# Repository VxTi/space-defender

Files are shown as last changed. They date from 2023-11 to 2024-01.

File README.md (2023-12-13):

# 🎮 TI Game Controller

De opdracht van Technische Informatica (TI) bestaat uit het ontwikkelen van een niet al te ingewikkelde browser-spel welke je gaat aansturen met je zelf gemaakt controller!

Aan dit project werk je in een tweetal, waarbij je onze Gitlab omgeving gebruikt
voor het bijhouden van je code, documentatie en planning.

## 📁 Bestandsstructuur

In deze repository krijgen jullie een structuur aan bestanden, hierbij mag je zelf wijzigingen maken in de bestanden die je nodig hebt.
De structuur is als volgt:

- `docs`: Hierin kan je de documentatie kwijt voor jouw project. Hiervan wordt een website gegenereerd die je kan vinden onder 'Pages' (Deploy > Pages).
- `teamdocumentatie`: In deze map kan je (markdown!) documenten kwijt die gaan over de samenwerking in het team, wat je niet op je gegenereerde website wilt hebben.
- `arduino`: Hierin kan je de code kwijt voor jouw project wat te maken heeft met je embedded systeem, code geschreven in Arduino.
- `web`: Hierin kan je de code kwijt voor jouw project wat te maken heeft met de webapplicatie, bijvoorbeeld HTML, CSS en Javascript.
- `server`: Hier kan je je server applicatie kwijt die gaat zorgen voor de verbinding tussen jouw embedded systeem, web-applicatie en database.

## 📝 Opdracht

De opdracht vinden jullie in de map `docs` onder `opdracht.md`. Hierin staat de opdracht beschreven en de eisen waaraan je moet voldoen. Beter is om de opdracht te bekijken via `Deploy` > `Pages`, en vervolgens te navigeren naar de opdracht.

Daarnaast vind je in dit Gitlab-project:

- User Stories (Plan > Issues)
- Learning Stories (Plan > Issues)
- Scrum Board (Plan > Boards)
- Sprints (Plan > Milestones)

## 📚 Documentatie

Naast het schrijven van commentaar in je code ga je ook aan de slag met het schrijven van documentatie. Dit doe je door in de map `docs` een Markdown bestand aan te maken. Dit bestand wordt automatisch omgezet naar een website die je kan vinden onder 'Pages' (Deploy > Pages).

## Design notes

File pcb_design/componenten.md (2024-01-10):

# Componenten

RGB LED: https://www.tinytronics.nl/shop/nl/componenten/led's/led's/rgb-led-5mm-diffuus-common-cathode
Battery level: https://randomnerdtutorials.com/power-esp32-esp8266-solar-panels-battery-level-monitoring/

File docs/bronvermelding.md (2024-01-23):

# Bronvermelding

## Informatiebronnen
- Wikipedia | Defender<br>
  https://en.wikipedia.org/wiki/Defender_(1981_video_game)

- KiCad | Introduction to KiCad<br>
  https://docs.kicad.org/6.0/en/getting_started_in_kicad/getting_started_in_kicad.html

- Squidfunk | MkDocs Material<br>
  https://squidfunk.github.io/mkdocs-material/reference/

- Sidorares | node-mysql2 Documentation<br>
  https://sidorares.github.io/node-mysql2/docs/documentation

- Random Nerd Tutorials | Power ESP32/ESP8266 with Solar Panels and Battery Level Monitoring<br>
  https://randomnerdtutorials.com/power-esp32-esp8266-solar-panels-battery-level-monitoring/

- Hackster.io | ESP32 BLE HID Device<br>
  https://www.hackster.io/user0448083246/esp32-ble-hid-keyboard-37a103

- HvA HBO-ICT | Knowledgebase HBO-ICT<br>
  https://knowledgebase.hbo-ict-hva.nl/

## Gebruikte assets
- FreeSound, LittleRobotSoundFactory | 8-Bit Sound Effects Library<br>
  https://freesound.org/people/LittleRobotSoundFactory/packs/16681/

- Dafond | Arcade Ya Font<br>
  https://www.dafont.com/arcade-ya.font

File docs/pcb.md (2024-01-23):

# Custom PCB design

## Inleiding
Voor dit project hebben wij onszelf uitgedaagd om zelf een PCB te ontwerpen voor de game controller. Dit hebben we gedaan met het programma KiCad. Dit is een gratis CAD programma waarmee je PCBs kunt ontwerpen. Het is een open source programma en wordt veel gebruikt door hobbyisten. Het is een erg uitgebreid programma en heeft veel mogelijkheden. Het is een erg goed programma om mee te beginnen als je nog nooit een PCB hebt ontworpen.

## PCB ontwerp
Wij hebben twee ontwerpen gemaakt. De allereerste was best wel mislukt en inefficient. Daarnaast was deze ook veels te groot aangezien we niet goed wisten hoe we het moesten aanpakken. De tweede versie was een stuk beter en efficienter. Deze hebben we ook daadwerkelijk op school laten printen. De eerste versie hebben we niet laten printen omdat deze niet goed was. Hieronder zie je de eerste versie van het PCB ontwerp.

## Designs

!!! note "Versie 1"
    Schematic 1 PCB 1

!!! note "Versie 2"
    Schematic 2 PCB 2

## PCB laten printen
In eerste instantie wilden we de PCB bestellen bij Jlcpcb. Dit is een bedrijf dat PCBs print en ze naar je opstuurt. Het enige nadeel was dat deze uit China moesten komen en dat het dus erg lang zou duren voordat we ze binnen zouden krijgen, daarnaast kost het ook geld. We hebben toen besloten om de PCB te laten printen op school. Dit was gratis en we konden het binnen twee dagen al ophalen. Het enige nadeel aan de PCB die we op school hebben laten printen is dat de kwaliteit niet zo goed is. De koperbanen zijn bloodgesteld en de PCB is niet gelamineerd. Daarnaast zijn de pads niet doorverbonden van de voorkant naar de achterkant, dus als je iets aan de achterkant zou solderen zou de voorkant niet werken. Om deze reden kunnen we helaas niet een werkende draadloze controller laten zien op de product review.

## Onderdelen
Hier een lijst met onderdelen:

| Aantal | Onderdeel |
| :----- | :--- |
| 2x | :material-fence-electric: Female headers 24x1 |
| 1x | :material-chip: ESP32S3 Dev Module |
| 1x | :material-integrated-circuit-chip: TP4056 battery management module  |
| 1x | :material-battery: 1250mAh 3.7V LiPo batterij |
| 1x | :material-toggle-switch: On/Off Switch |
| 7x | :material-gesture-tap-button: Non-Latching Push Button |
| 1x | :material-led-on: RGB LED |
| 1x | :material-resistor: 100 k:material-omega: weerstand |
| 1x | :material-resistor: 27 k:material-omega: weerstand |
| 3x | :material-resistor: 47 :material-omega: weerstand |
| 7x | :material-resistor: 500 :material-omega: weerstand |

## Resultaat
Hieronder zie je het resultaat van de PCB die we op school hebben laten printen. De PCB ziet er niet uit zoals je gewend bent, hij is niet standaard groen en de koperbanen zijn blootgesteld. We hebben alle componenten erop gesoldeerd. Sommige knoppen waarvan de tracks aan de achterkant lopen doen het wel, maar de knoppen waarvan de tracks aan de voorkant lopen doen het niet. Dit komt omdat de pads niet doorverbonden zijn. We hebben de PCB getest met een ESP32S3 Dev Module en de meeste functies werken. Stel dat we een PCB hadden die wel doorverbonden pads had weten we zeker dat dit design een succes was geweest.

Resultaat

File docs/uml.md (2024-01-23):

# UML

## Database EER Diagram
DB

## Class Diagram
Class Diagram

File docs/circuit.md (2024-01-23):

# Elektrische schakeling Game controller

Hieronder is de elektrische schakeling van de game controller te zien. Ook deze hebben wij gemaakt met behulp van het gratis CAD programma KiCad. KiCad heeft zelf al heel veel elektrische componenten ingebouwd waarmee je kunt werken. Helaas konden wij nergens van KiCad zelf de ESP32 vinden. De schematics en blueprints voor alle Espressif (Fabrikant van onder andere de ESP32) zijn te vinden op de GitHub van Espressif. De download link hebben we [hier voor je](https://github.com/espressif/kicad-libraries/releases/download/2.0.6/espressif-kicad-addon.zip).

!!! note "Circuit" 
    Game controller

### Pin Schema
| ESP32 Pin | Doel |
| :--- | :--- |
| `21` | :material-gesture-tap-button: DPAD UP Knop |
| `38` | :material-gesture-tap-button: DPAD LEFT Knop |
| `45` | :material-gesture-tap-button: DPAD RIGHT Knop |
| `42` | :material-gesture-tap-button: DPAD DOWN Knop |
| `7` | :material-gesture-tap-button: Primary A Knop |
| `6` | :material-gesture-tap-button: Secondary B Knop |
| `4` | :material-gesture-tap-button: Option Knop |
| `5` | :material-battery-unknown-bluetooth: Accu spanningsmeter |
| `35` | :material-led-on: RGB LED - Rood PWM Signaal |
| `36` | :material-led-on: RGB LED - Groen PWM Signaal |
| `37` | :material-led-on: RGB LED - Blauw PWM Signaal |

Op dit schema zit alles er wellicht een beetje ongeorganiseerd uit, en dat kan in die zin ook kloppen. Echter heeft dit een reden. Bij het ontwerpen van een PCB moet je altijd eerst een schematic maken zodat het programma weet wat met wat is verbonden. De reden dat wij soms pins op de schematic hebben gekozen die totaal aan de andere kant liggen komt omdat deze dan op de PCB vaak wel recht naast de knopjes bijvoorbeeld liggen. Zo zijn de tracks in de pcb zo kort mogelijk, want lange tracks hebben vaker last van noise en een hoge weerstand.

Het ontwerp in deze schematic is dus ook letterlijk schematisch gemaakt en niet praktisch zoals het PCB ontwerp. De Espressif library maakt hun blueprints dus op deze manier om bepaalde pins met enigzins dezelfde functionaliteit bij elkaar weer te geven zodat het makkelijk is om deze te onderscheiden. Wij maken hier in dit geval geen gebruik van aangezien wij alleen Input en Output pins nodig hebben, en dit ondersteunen alle GPIO Pins op de ESP32 wel.

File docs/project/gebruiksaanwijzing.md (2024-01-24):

# Game controller gebruiksaanwijzing.

Controller

## Inleiding
Dit is de game controller die wij gedurende blok 2 hebben ontwikkeld. Zoals je op de foto kunt zien is de controller geheel draadloos te gebruiken door middel van een Bluetooth Low Energy verbinding. Alle componenten kun je vinden in de PCB documentatie.

## Gebruikswijze
De controller is te gebruiken met alle games die gebruik maken van de WASD toetsenbord layout. De controller emuleert als het ware een Bluetooth toetsenbord, waardoor deze heel makkelijk te implementeren was in ons spel. Daarnaast is deze ook meteen compatible met alle andere games die gebruik maken van de WASD layout.
Wanneer je de controller aanzet met de ON/OFF switch zal deze meteen in koppelmodus (pairing) gaan. Je zult vanzelf op jouw apparaat zien wanneer de controller verbonden is.

## Batterij
De controller maakt gebruik van een 3.7V LiPo batterij. Deze batterij is op te laden met een USB-C kabel met een spanning van 5 Volt. Je kunt dus de meest hedendaagse opladers gebruiken om de controller op te laden. De controller heeft een ingebouwde batterij indicator die je kunt zien wanneer je de controller aan het opladen bent. Dan zal er een rode LED branden op de oplaad module. Wanneer de controller volledig is opgeladen zal deze LED blauw worden.

## Knoppen
De controller heeft 7 knoppen. 4 van deze knoppen zijn de D-PAD knoppen. Deze knoppen zijn de pijltjes toetsen op een toetsenbord. De andere 3 knoppen zijn de A, B en Option knoppen. De A knop emuleert Spatie, en de B knop emuleert F. Tot slot emuleert de Option knop de R knop. Deze knoppen zijn allemaal te zien op de foto hierboven.

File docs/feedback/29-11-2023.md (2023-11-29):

* Feedback op 29-11-2023

** Sebas:

Beweging mag wat sneller, vloeiender
Input lag is naar Sebas' idee niet aanwezig

** Dano:

Ziet er goed uit
Springen mag hoger
Input lag is ook naar Dano's idee ook niet aanwezig

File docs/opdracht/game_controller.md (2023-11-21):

# Game Controller

Wanneer je denkt aan een Game Controller denk je misschien wel aan de controller van jouw favoriete game console. Deze controllers zijn vaak gemaakt van plastic en bevatten een aantal knoppen en joysticks. Onderdeel van deze opdracht is dat jullie zelf een game controller gaan maken, hoe deze echter eruit gaat zien bepalen jullie.

Om jullie een vlotte start te geven met het bouwen krijgen jullie van ons een moederbord waarop ruimte zit voor een aantal vaste componenten. Dit document geeft je alle details over het gebruik van dit moederbord en de componenten die erop zitten. Daarnaast vind je in dit document ook een aantal voorbeelden van hoe je de componenten kan gebruiken.

## Printed Circuit Board (PCB)

Het moederbord dat jullie krijgen is een Printed Circuit Board (PCB). Dit is een bord waarop een aantal componenten zijn geplaatst. Deze componenten zijn met elkaar verbonden door middel van koperen sporen. Deze sporen zorgen ervoor dat de componenten met elkaar kunnen communiceren. Dit zorgt ervoor dat je geen losse draden hoeft te gebruiken om de componenten met elkaar te verbinden, zoals je misschien wel gewend bent van de breadboard.

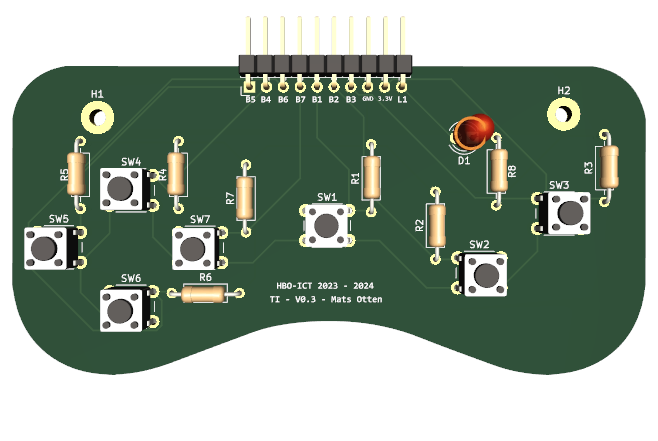
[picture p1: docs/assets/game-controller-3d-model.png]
3d model


## Ontwerp

Bij het ontwerp van de PCB is er rekening gehouden met vooral drukknoppen die op strategische wijze zijn geplaatst om ervoor te zorgen dat je veel voorkomende spellen zou kunnen aansturen. Voor elke drukknop is er ruimte voor een weerstand.

Dan heb je ook de mogelijkheid om een LED aan te sluiten, deze zouden jullie bijvoorbeeld kunnen gebruiken om een status door te geven. Om deze LED goed te kunnen gebruiken is er ook ruimte voor een voorschakelweerstand.

Dan is er aan één kant een rij van pin-headers opgenomen, deze staan in een hoek van 90 graden, zodat je hier een kabel kan aansluiten zonder dat deze in de weg komt te staan van de andere componenten.

Om ervoor te zorgen dat je het PCB ergens in vast kan monteren, of misschien wel om iets te bevestigen aan de PCB, vind je 2 schroefgaten aan de bovenkant van het PCB.

## Aansluitschema

In het aansluitschema is rekening gehouden met de volgende componenten:

| Naam | Omschrijving |
| --- | --- |
| SW1 | Drukknop #1 (pinheader B1) |
| SW2 | Drukknop #2 (pinheader B2) |
| SW3 | Drukknop #3 (pinheader B3) |
| SW4 | Drukknop #4 (pinheader B4) |
| SW5 | Drukknop #5 (pinheader B5) |
| SW6 | Drukknop #6 (pinheader B6) |
| SW7 | Drukknop #7 (pinheader B7) |
| D1 | LED (pinheader L1) |
| Pin-header | B1-7, L1, 3.3V, GND |
| H1 | Schroefgat #1 |
| H2 | Schroefgat #2 |

Het aansluitschema van het PCB is als volgt:

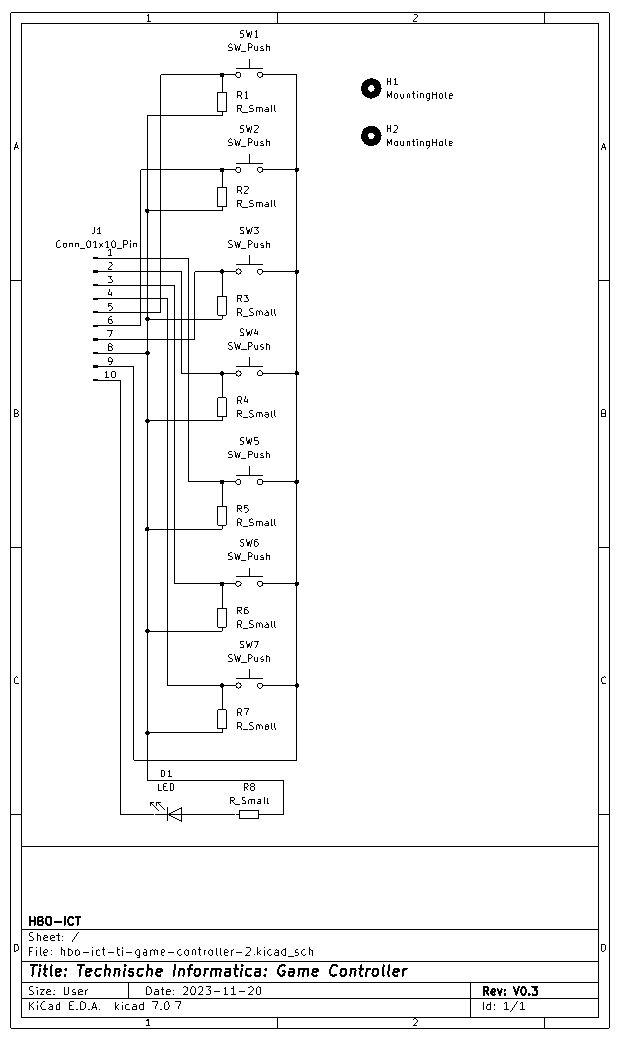
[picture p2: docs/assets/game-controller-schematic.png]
schematic


## PCB layout

De layout van het PCB is als volgt:

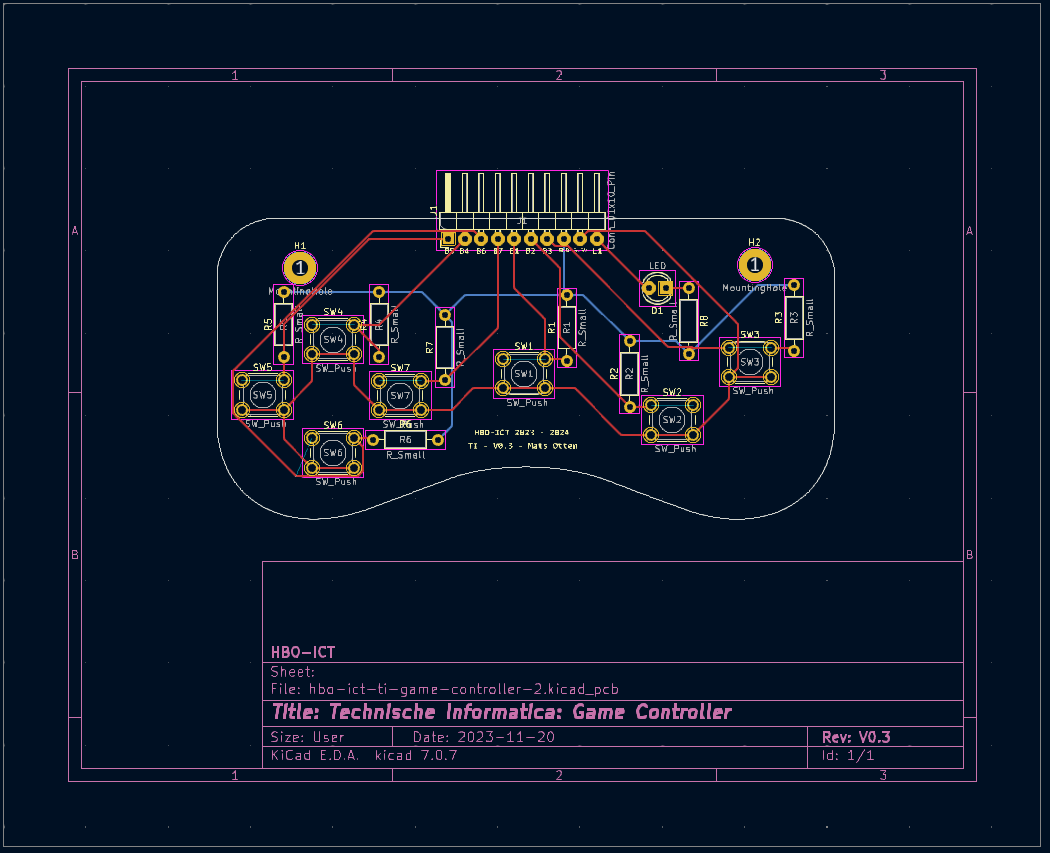
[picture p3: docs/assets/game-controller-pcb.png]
pcb


{{ mdocotion_header('/assets/headers/game_controller_pcbs2.jpg') }}

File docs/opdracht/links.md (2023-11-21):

# Links

Op deze pagina vind je een overzicht van handige links die van pas kunnen komen bij het maken van de opdracht.

## Project management

- [Knowledgebase: Git](https://knowledgebase.hbo-ict-hva.nl/1_beroepstaken/software/manage_and_control/git/0_git/)
    - Bij een project waar je te maken hebt met teamgenoten is het goed gebruik maken van Git alleen maar belangrijker.

## Programmeren

- [Knowledgebase: HTML](https://knowledgebase.hbo-ict-hva.nl/1_beroepstaken/software/realiseren/talen/declaratieve_talen/html/)
- [Knowledgebase: CSS](https://knowledgebase.hbo-ict-hva.nl/1_beroepstaken/software/realiseren/talen/declaratieve_talen/css/)
- [Knowledgebase: Basis principes](https://knowledgebase.hbo-ict-hva.nl/1_beroepstaken/software/realiseren/basis_principes/0_basis_principes/)

## Libraries

- [Knowledgebase: Javascript: P5](https://knowledgebase.hbo-ict-hva.nl/1_beroepstaken/software/realiseren/platformen/p5.js/0_p5js/)
- [Arduino: ArduinoJSON](https://arduinojson.org/)
- [Arduino: WebSockets](https://www.arduino.cc/reference/en/libraries/websockets/)
- [Python: Websockets](https://websockets.readthedocs.io/en/stable/intro/index.html)

## Overige

- [Localtunnel](https://theboroer.github.io/localtunnel-www/)
    - Wanneer je een server draait op het netwerk van de HvA mag je niet zomaar van buitenaf verbinding maken. Met localtunnel kun je een tunnel maken naar een publieke URL. Zo kun je toch van buitenaf verbinding maken met je server.
- [Oege](https://oege.ie.hva.nl/)
    - Oege is onze eigen cloud omgeving waar jij als HBO-ICT student een MySQL database kan krijgen en SSH toegang tot een Linux server.

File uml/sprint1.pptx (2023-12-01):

## TI Platformer

Door Luca Warmenhoven en Just Koopen

## Mindmap

- Nog niet veel onderzoek gedaan

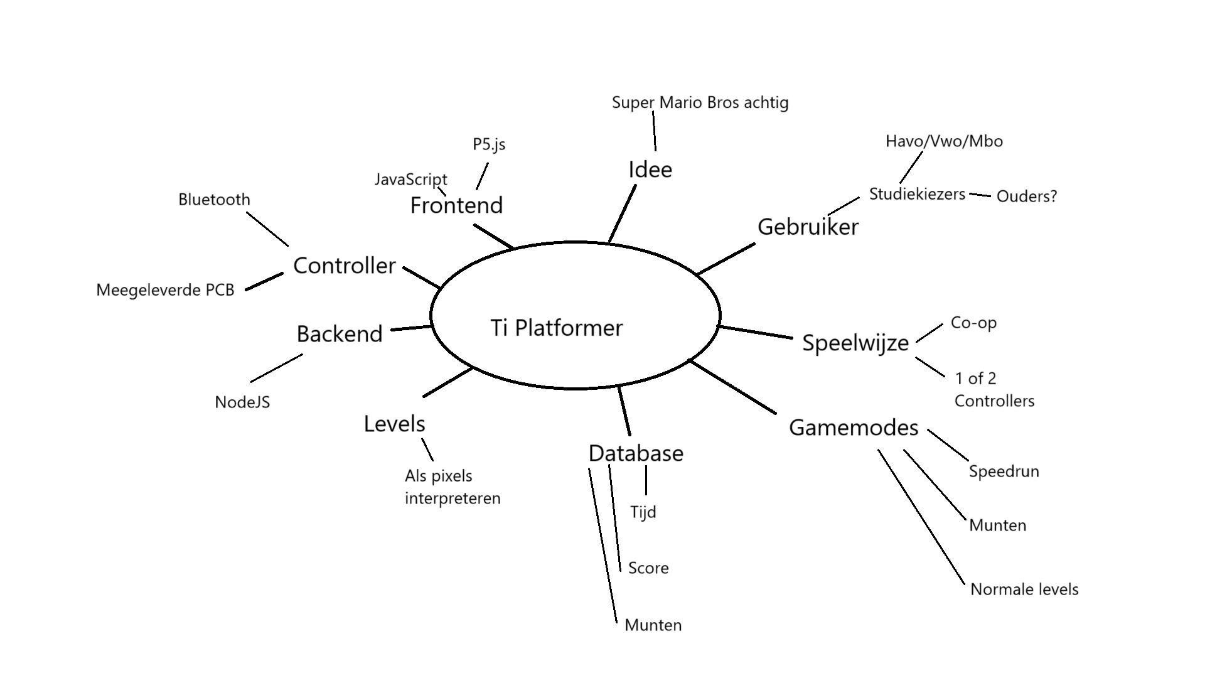
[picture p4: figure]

## Wireframe

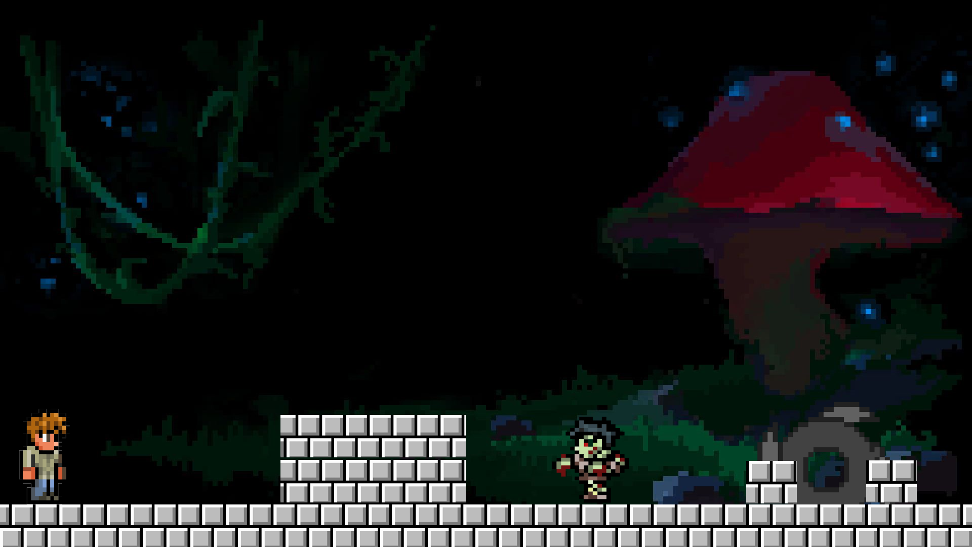
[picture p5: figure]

Concept

## Flow chart werkwijze

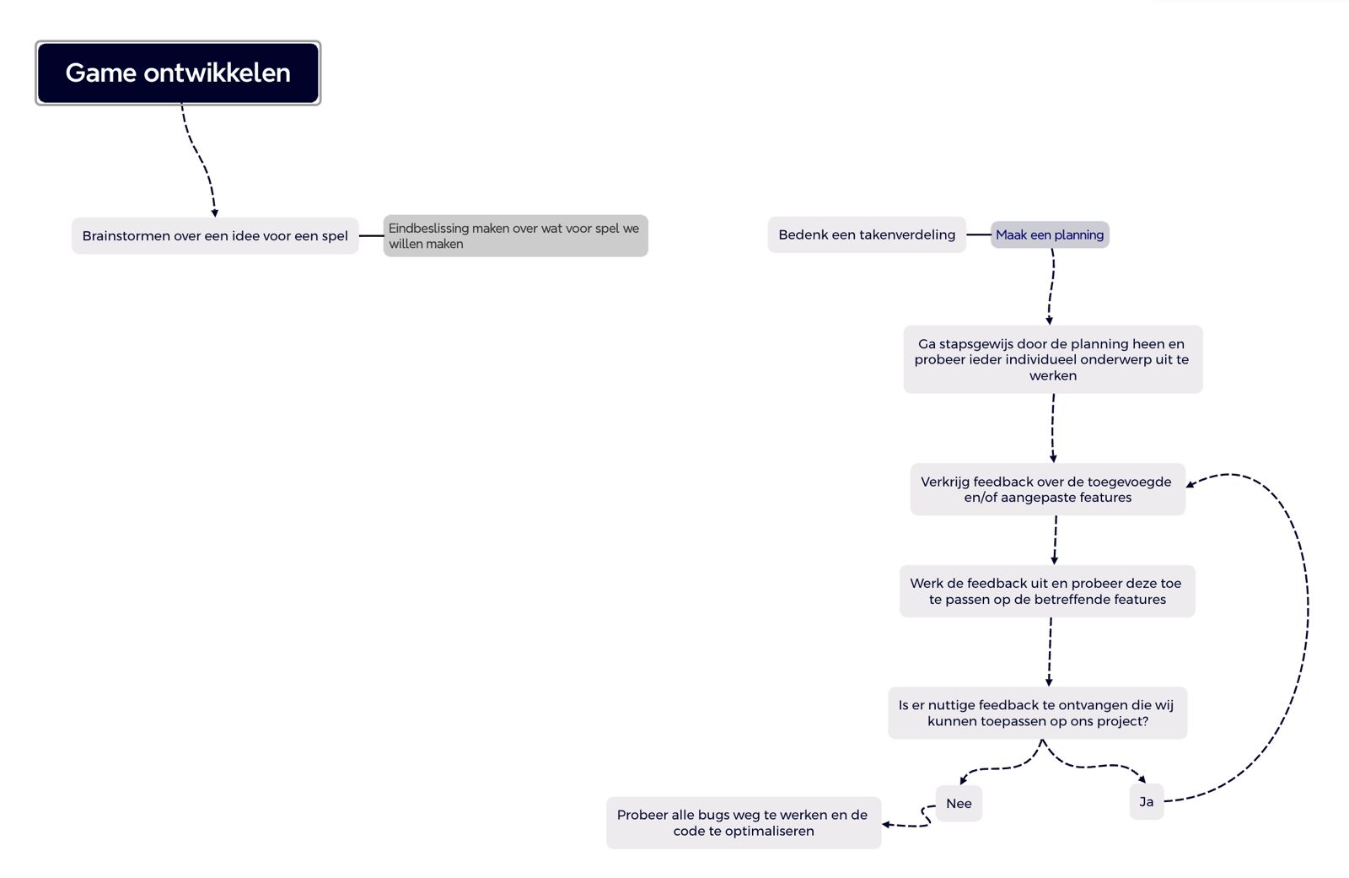
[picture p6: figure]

## Documentatie

Gebruiksaanwijzing

## Prototype

Platformer
Minecraft textures
Mario Bros speelwijze

## Eerste guerilla test, feedback.

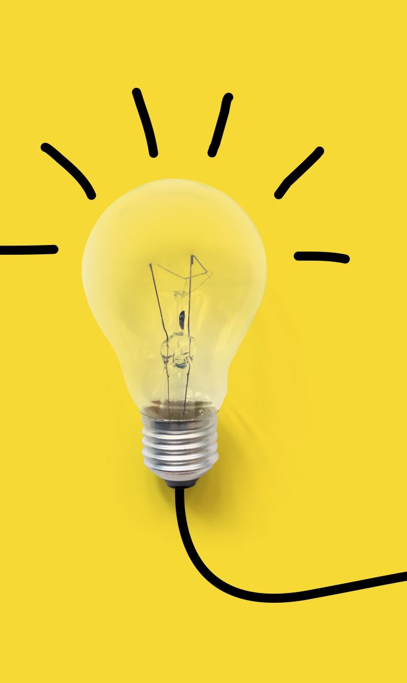
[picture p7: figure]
Gloeilamp op een gele achtergrond met geschetste lichtbundels en een kabel

- Persoon 1:
Beweging mag wat sneller, vloeiender
Input lag is naar persoon zijn idee niet aanwezig
- Persoon 2:
Ziet er goed uit
Springen mag hoger
Input lag is ook naar persoon zijn idee ook niet aanwezig

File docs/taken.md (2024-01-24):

# Taken voor komende periode

!!! note "Schrijf een testplan"
    Hiermee moeten wij kwalitatief met zo min mogelijk invloed feedback verkrijgen van gebruikers 
    om deze non-biased te maken. Dit moeten wij doen door middel van telkens
    dezelfde vragen te stellen.
    - Afgerond [X]

!!! note "Verkrijg meer feedback"
    Dit spreekt voor zich, we moeten meer mensen benaderen om feedback
    van te verkrijgen.
    - 80%

!!! note "Database uitbreiden"
    Meer tabellen toevoegen, deze aan elkaar linken. <br>
    Ook moeten de tabellen aangemaakt worden als de server start, indien
    deze nog niet aanwezig zijn.
    - Afgerond [X]

!!! note "Documentatie uitbreiden"
    Ook redelijk vanzelfsprekend, meer documentatie schrijven over de
    code en game functionaliteit.
    - Afgerond [X]

!!! note "UML bestanden beter weergeven"
    Deze bestanden moeten we in de documentatie plaatsen.
    - Afgerond [X]

!!! note "Eigen User-Stories aanmaken"
    We moeten afhankelijk van feedback user-stories creëren
    - 2/3

!!! note "PCB Design documenteren"
    PCB design documenteren en uitleggen etc..
    - Afgerond [X]

!!! note "UML diagrammen in markdown zetten"
    UML diagrammen in markdown zetten zodat deze op de pages staan.
    - Afgerond [X]

!!! note "Nieuwe game ontwerp documenteren"
    Nieuwe game ontwerp documenteren met gebruiksaanwijzing enz
    - Afgerond [X]

!!! note "Bronvermelding maken"
    Alle bronnen die we gebruikt hebben in de documentatie zetten. Check knowledgebase hoe dat moet.
    - Afgerond [X]

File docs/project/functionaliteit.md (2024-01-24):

# Game functionaliteit

### Wat doet ons spel, en hoe speel je het?

Om te beginnen is het handig om duidelijk te maken hoe je het spel moet 
gaan bedienen.

Er zijn meerdere manieren om het spel te besturen, al heb je geen controller
tot je beschikking is het altijd mogelijk om de `A` en `D` toetsen te gebruiken om 
links (`A`) en rechts (`D`) te gaan, `SHIFT` om te sneaken (langzamer lopen) en 
`SPATIE` om te springen.

Indien je wel tot de controller beschikt zijn al deze bewegingen uiteraard
nogsteeds mogelijk, alleen dien je dan andere knoppen te gebruiken.

Hierbij is de `DPAD` om je rechts, links etc te bewegen. Option is om te pauzeren. A is schieten of selecteren en B is jouw ability.

### How to play

Voor alle individuen geinterresseerd in het programmeer gedeelte van ons project
hebben wij hier een zeer uitgebreide beschrijving voor alle onderdelen van ons game project.

Al start je het spel, dan kom je in het hoofdmenu. Hier kan je kiezen uit 3 opties:
- Play
- Scores
- How to play

In het 'How to play' menu staat uitgebreid beschreven hoe het spel werkt.

In het 'Scores' menu kan je de highscores zien van alle spelers die het spel hebben gespeeld.

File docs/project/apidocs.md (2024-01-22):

# Hoe gebruik je de API?

De API dient als tussenlaag tussen de game en de database. De game stuurt een request naar de API, en de API stuurt een request naar de database. De API stuurt de response van de database terug naar de game. De game kan dus niet direct communiceren met de database, maar moet altijd via de API. Dit is gedaan omdat het niet veilig is om de database direct te laten communiceren met de game. De code van de game kan namelijk door iedereen worden bekeken, en als de game direct communiceert met de database, kan iedereen dus ook de database zien. Dit is niet veilig, en daarom is de API ertussen gezet. De game communiceert met de API, en de API communiceert met de database. De code van de API is niet openbaar, en dus kan niemand de database zien.

### Gebruikswijze
De API is te gebruiken door een request te maken naar het adres: `http://oege.ie.hva.nl:8081/api`. Voor een lijst met URLs moet je een stukje verder lezen.

### Probeer de API
Wij hebben tijdens het ontwikkelen van de API het programma Postman gebruikt. Hierin kun je heel gemakkelijk requests sturen naar de API, en de response bekijken. Dit is heel handig om de API te testen. Je kunt Postman downloaden op de volgende website: [https://www.postman.com/downloads/](https://www.postman.com/downloads/)

### Niet bestaande URL
Als je een niet bestaande URL probeert te gebruiken, zal de API HTTP status 404 (Not Found) terugsturen, en een JSON-object waarin staat dat de URL niet bestaat.

# Beveiliging

## Beveiliging d.m.v. een API key

De API is beveiligd met een API key. Deze API key is te verkrijgen door een request naar de API te sturen, de specifieke request kun je in de documentatie vinden onder het kopje 'Alle API URLs'. Om deze aan te maken heb je het Oege wachtwoord nodig van de admin. De API key is een unieke string die je moet meesturen in elke request die je naar de API stuurt.

!!! failure "API key"
        Als je geen API key meestuurt, of een verkeerde API key, zal de API HTTP status 401 (Unauthorized) terugsturen, en een JSON-object waarin staat dat je niet geautoriseerd bent.

## Beveiliging d.m.v. een rate limit

Naast een unieke API key, heeft de API ook een rate limit. Dit betekent dat je maar een bepaald aantal requests per seconde mag sturen. Als je meer requests stuurt dan het aantal dat is toegestaan, zal de API HTTP status 429 (Too Many Requests) terugsturen, en een JSON-object waarin staat dat je te veel requests hebt gestuurd. 
Het aantal requests dat je mag sturen per seconde is momenteel tien. 
Als je meer dan 600 requests per minuut stuurt, zal de API HTTP status 429 (Too Many Requests) terugsturen, en een JSON-object waarin staat dat je te veel requests hebt gestuurd.

!!! warning "Rate limit"
    De rate limit is gebonden aan jouw IP adres. Als je dus met meerdere mensen op hetzelfde netwerk zit, en je stuurt allemaal requests naar de API, dan kan het zijn dat je rate limited wordt.

De rate limit is laag genoeg dat de game er geen last van zal hebben. De game stuurt namelijk maar één request per keer. De game stuurt alleen een request als de gebruiker een nieuw record heeft gezet. Dit zal niet vaak gebeuren, en dus zal de game niet snel de rate limit bereiken. Het is puur en alleen ter beveiliging dat iemand niet zomaar de hele API kan flooden met requests.

Als je ge-rate-limited bent krijg je een JSON-object terug waarin staat dat je te veel requests stuurt.

## Beveiliging tegen SQL injection

De API is beveiligd tegen SQL injection. Dit betekent dat je geen SQL code kunt uitvoeren door middel van de API. Dit is gedaan door middel van prepared statements. Dit betekent dat de SQL code die wordt uitgevoerd, niet wordt uitgevoerd met de data die je meestuurt in de request. De data wordt eerst gecontroleerd, en daarna pas wordt de SQL code uitgevoerd. Hierdoor is het niet mogelijk om SQL code uit te voeren door middel van de API.

!!! failure "SQL injection"
    Doormiddel van prepared statements is het niet mogelijk om SQL code uit te voeren door middel van de API. SQL commando's die je meestuurt in de request zullen niet worden uitgevoerd, omdat deze eerst worden gecontroleerd.

# Alle API URLs

Hieronder staan alle URLs die je kunt gebruiken om data op te vragen of te wijzigen in de database. Alle requests moet je sturen als POST request, omdat je in een POST request veel meer data kan stoppen dan in een GET request. Daarnaast is het ook veiliger om een POST request te sturen, omdat je dan de data in de body van de request kan stoppen, en niet in de URL. Alle API calls zijn als volgt:

!!! note "Creëer een API key"
    ## Creëer een API key

    Deze URL is bedoeld om een API key te creëren. Je moet een JSON-object sturen met het wachtwoord. De API zal een JSON-object terugsturen met de status van de request. De URL is als volgt: `http://oege.ie.hva.nl:8081/api/createkey`. De API verwacht de volgende header: `Content-Type: application/json` en de volgende data als JSON object:

    ```json
    {
        "password": "WACHTWOORD"
    }
    ```
    Als de key en/of het wachtwoord niet overeenkomt, zal de API HTTP status 401 (Unauthorized) terugsturen, en een JSON-object waarin staat dat je niet geautoriseerd bent.
    Als je wel de juiste data stuurt, zal de API HTTP status 201 (Created) terugsturen, en een JSON-object waarin staat dat de key succesvol is aangemaakt. Deze ziet er als volgt uit:

    ```json
    {
        "message": "New API key created",
        "key": "NIEUWE APIKEY"
    }
    ```

!!! note "Verwijder een API key"
    ## Verwijder een API key

    Deze URL is bedoeld om een API key te verwijderen. Je moet een JSON-object sturen met de key en het wachtwoord. De API zal een JSON-object terugsturen met de status van de request. De URL is als volgt: `http://oege.ie.hva.nl:8081/api/deletekey`. De API verwacht de volgende header: `Content-Type: application/json` en de volgende data als JSON object:

    ```json
    {
        "key": "APIKEY"
    }
    ```

    Als de key niet overeenkomt, zal de API HTTP status 401 (Unauthorized) terugsturen, en een JSON-object waarin staat dat je niet geautoriseerd bent.
    Als de key wel overeenkomt, zal de API HTTP status 202 (Accepted) terugsturen, en een JSON-object waarin staat dat de ingevulde key succesvol is verwijderd. Deze ziet er als volgt uit:

    ```json
    {
        "message": "API key deleted"
    }
    ```

!!! note "Pas de laatste score van een gebruiker aan"
    ## Pas de laatste score van een gebruiker aan

    Deze URL is bedoeld om de score van een gebruiker te updaten naar de meegeleverde waarde. Je moet een JSON-object sturen met de key, de userId van wie je de score gaat aanpassen, de nieuwe score en de nieuwe coins. De API zal een JSON-object terugsturen met de status van de request. De URL is als volgt: `http://oege.ie.hva.nl:8081/api/updatescore`. De API verwacht de volgende header: `Content-Type: application/json` en de volgende data als JSON object:

    ```json
    {
        "key": "APIKEY",
        "userId": "USERID",
        "score": "SCORE",
        "wave": "WAVE"
    }
    ```

    Als de key niet overeenkomt, zal de API HTTP status 401 (Unauthorized) terugsturen, en een JSON-object waarin staat dat je niet geautoriseerd bent.
    Als de key wel overeenkomt, zal de API HTTP status 201 (Created) terugsturen, en een JSON-object waarin staat dat de ingevulde key succesvol is verwijderd. Deze ziet er als volgt uit:

    ```json
    {
        "message": "Last score updated"
    }
    ```

    Daarnaast zal de backend server na het updaten van de laatste score meteen checken als deze hoger is dan de highscore van de gegeven speler. Als deze nieuwe score hoger is dan de vorige score zal deze automatisch aangepast worden in de database.

!!! note "Creëer een nieuwe gebruiker"
    ## Creëer een nieuwe gebruiker

    Deze URL is bedoeld om een nieuwe gebruiker aan te maken in de database. Je moet een JSON-object sturen met de key, de naam en het emailadres van de nieuwe gebruiker. De API zal een JSON-object terugsturen met de status van de request. De URL is als volgt: `http://oege.ie.hva.nl:8081/api/createuser`. De API verwacht de volgende header: `Content-Type: application/json` en de volgende data als JSON object:
    
    ```json
    {
        "key": "APIKEY",
        "name": "NAAM",
        "email": "EMAIL"
    }
    ```

    Als de key niet overeenkomt, zal de API HTTP status 401 (Unauthorized) terugsturen, en een JSON-object waarin staat dat je niet geautoriseerd bent.
    Als de key wel overeenkomt, zal de API HTTP status 201 (Created) terugsturen, en een JSON-object waarin staat dat de ingevulde key succesvol is verwijderd. Deze ziet er als volgt uit:

    ```json
    {
        "message": "New user created",
        "userId": "USERID"
    }
    ```
    Als de gebruiker al bestaat, zal de API HTTP status 400 (Bad request) terugsturen, en een JSON-object waarin staat dat de gebruiker al bestaat. Deze ziet er als volgt uit:

    ```json
    {
        "message": "User already exists"
    }
    ```

!!! note "Verkrijg alle data van een gebruiker"
    ##  Verkrijg alle data van een gebruiker
    
    Om snel en gemakkelijk alle data van een gebruiker te verkrijgen dient de API gebruiker
    simpelweg een verzoek te sturen naar `http://oege.ie.hva.nl:8081/api/getuser` met de
    een header 'Content-Type: application/json' en een JSON object met de key en de userId.
    Dit object ziet er als volgend uit:
    ```json
    {
        "key": "APIKEY",
        "userId": "USERID",  - of -  "name": "NAAM",
    }
    ```
    De gebruiker kan zowel 'name' als 'userId' gebruiken om de gebruiker te identificeren.
    Als de gebruiker niet bestaat zal de API HTTP status 400 (Bad request) terugsturen, en een JSON-object waarin staat dat de gebruiker niet bestaat. Deze ziet er als volgt uit:
    ```json
    {
        "message": "User does not exist"
    }
    ```
    Indien de gebruiker wel bestaat zal de API HTTP status 200 (OK) terugsturen, en een JSON-object waarin staat dat de gebruiker succesvol is opgehaald. Deze ziet er als volgt uit:
    ```json
    {
        "message": "User retrieved",
        "user": {
            "userId": "USERID",
            "userName": "NAAM",
            "lastScore": "LAATSTE SCORE",
            "lastCoins": "LAATSTE COINS",
            "maxScore": "HIGHSCORE",
            "maxCoins": "HIGHCOINS"
        }
    }
    ```

!!! note "Verwijder een gebruiker"
    ## Verwijder een gebruiker

    Deze URL is bedoeld om een bestaande gebruiker te verwijderen. Je moet een JSON-object sturen met de userId van de gebruiker die je wilt verwijderen, en jouw API key. De API zal een JSON-object terugsturen met de statys van de request. De URL is als volgt: `http://oege.ie.hva.nl:8081/api/deleteuser`. De API verwacht de volgende header: `Content-Type: application/json` en de volgende data als JSON object:
    
    ```json
    {
        "key": "APIKEY",
        "userId": "USERID"
    }
    ```

    Als de key niet overeenkomt, zal de API HTTP status 401 (Unauthorized) terugsturen, en een JSON-object waarin staat dat je niet geautoriseerd bent.
    Als de key wel overeenkomt, zal de API HTTP status 202 (Accepted) terugsturen, en een JSON-object waarin staat dat de ingevulde key succesvol is verwijderd. Deze ziet er als volgt uit:

    ```json
    {
        "message": "User deleted"
    }
    ```

!!! note "Check als een gebruiker bestaat"
    ## Check als een gebruiker bestaat

    Deze URL is bedoeld om te checken als een gebruiker al bestaat in de database. Je moet een JSON-object sturen met de key en een naam of userId. De API zal een JSON-object terugsturen met de status van de request. De URL is als volgt: `http://oege.ie.hva.nl:8081/api/deletekey`. De API verwacht de volgende header: `Content-Type: application/json` en de volgende data als JSON object:
    
    ```json
    {
        "key": "APIKEY",
        "idOrName": "USERID of NAAM"
    }
    ```

    Als de key niet overeenkomt, zal de API HTTP status 401 (Unauthorized) terugsturen, en een JSON-object waarin staat dat je niet geautoriseerd bent.
    Als de key wel overeenkomt, zal de API HTTP status 200 (OK) terugsturen, en een JSON-object waarin staat dat de ingevulde key succesvol is verwijderd. Deze ziet er als volgt uit:

    ```json
    {
        "message": "User exists",
        "exists": true || false
    }
    ```

!!! note "Krijg de laatste score van een gebruiker"
    ## Krijg de laatste score van een gebruiker

    Deze URL is bedoeld om de laatste score van een gebruiker op te vragen. Je moet een JSON-object sturen met de key en de userId van wie je de laatste score wilt krijgen. De API zal een JSON-object terugsturen met de status van de request. De URL is als volgt: `http://oege.ie.hva.nl:8081/api/getlastscore`. De API verwacht de volgende header: `Content-Type: application/json` en de volgende data als JSON object:
    
    ```json
    {
        "key": "APIKEY",
        "userId": "USERID"
    }
    ```

    Als de key niet overeenkomt, zal de API HTTP status 401 (Unauthorized) terugsturen, en een JSON-object waarin staat dat je niet geautoriseerd bent.
    Als de key wel overeenkomt, zal de API HTTP status 200 (OK) terugsturen, en een JSON-object waarin staat dat de ingevulde key succesvol is verwijderd. Deze ziet er als volgt uit:

    ```json
    {
        "message": "Last score retrieved",
        "lastScore": {
            "userId": "USERID",
            "userName": "NAAM",
            "lastScore": "LAATSTE SCORE",
            "lastWave": "LAATSTE WAVE"
        } 
    }
    ```

    Als de gebruiker niet bestaat zal de geneste JSON `lastScore` leeg zijn.

!!! note "Krijg de hoogste score van een gebruiker"
    ## Krijg de hoogste score van een gebruiker

    Deze URL is bedoeld om de highscore van een gebruiker op te vragen. Je moet een JSON-object sturen met de key en de userId van wie je de highscore wilt krijgen. De API zal een JSON-object terugsturen met de status van de request. De URL is als volgt: `http://oege.ie.hva.nl:8081/api/gethighscore`. De API verwacht de volgende header: `Content-Type: application/json` en de volgende data als JSON object:
    
    ```json
    {
        "key": "APIKEY",
        "userId": "USERID"
    }
    ```

    Als de key niet overeenkomt, zal de API HTTP status 401 (Unauthorized) terugsturen, en een JSON-object waarin staat dat je niet geautoriseerd bent.
    Als de key wel overeenkomt, zal de API HTTP status 200 (OK) terugsturen, en een JSON-object waarin staat dat de ingevulde key succesvol is verwijderd. Deze ziet er als volgt uit:

    ```json
    {
        "message": "High score retrieved",
        "highScore": {
            "userId": "USERID",
            "userName": "NAAM",
            "maxScore": "HIGHSCORE",
            "maxWave": "HOOGSTE WAVE"
        } 
    }
    ```

    Als de gebruiker niet bestaat zal de geneste JSON `highScore` leeg zijn.

!!! note "Verkrijg de leaderboards"
    ## Verkrijg de leaderboards aan de hand van een sortBy en een maxResults
    Deze URL is bedoeld om de leaderboards op te vragen. Je moet een JSON-object sturen met de key, het gene waar je op wilt sorteren, en  het maximaal aantal resultaten. De API zal een JSON-object terugsturen met de status van de request. De URL is als volgt: `http://oege.ie.hva.nl:8081/api/getleaderboards`. De API verwacht de volgende header: `Content-Type: application/json` en de volgende data als JSON object:
    
    ```json
    {
        "key": "APIKEY",
        "sortBy": "maxScore || maxWave",
        "maxResults": "AANTAL"
    }
    ```

    Als de key niet overeenkomt, zal de API HTTP status 401 (Unauthorized) terugsturen, en een JSON-object waarin staat dat je niet geautoriseerd bent.
    Als de key wel overeenkomt, zal de API HTTP status 200 (OK) terugsturen, en een JSON-object waarin staat dat de ingevulde key succesvol is verwijderd. Deze ziet er als volgt uit:

    ```json
    {
        "message": "Leaderboards retrieved",
        "leaderboards": [
            {
                "userId": "USERID",
                "userName": "NAAM",
                "maxScore": "HIGHSCORE",
                "maxWave": "MAX WAVE"
            },
            {
                "userId": "USERID",
                "userName": "NAAM",
                "maxScore": "HIGHSCORE",
                "maxWave": "MAX WAVE"
            },
            ...
        ]
    }
    ```

    Als er geen gebruikers zijn zal de geneste JSON `leaderboards` leeg zijn.

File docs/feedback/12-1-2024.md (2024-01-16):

## Feedback 12-01-2024

Verkregen feedback van mede HBO-ICT studenten.

--- 

> ### Anoniem 1
> 
> Zou het misschien het settings scherm updaten of weghalen, is momenteel nogal leeg..
> Super leuk spel!

> ### Anoniem 2
> 
> Misschien wat meer enemies toevoegen, of een boss, of verder gaan met het waves gedeelte
> Verder ziet het er allemaal zeer goed uit.

> ### Anoniem 3
> 
> Mogelijk het waves systeem afmaken, deze is nog niet zo goed geimplementeerd.
> Het settings ook afmaken

> ### Anoniem 4
> 
> De beweging van de spaceship misschien wat sneller laten vertragen, hij blijft nogal lang verder gaan

> ### Anoniem 5
> 
> Zou leuk zijn als je de statistieken van jezelf kan delen met anderen op een of andere manier.

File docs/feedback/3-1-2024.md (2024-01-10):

## Feedback 03-01-2024

--- 

> ### Anoniem 1
> Zou het aanraden om in de game perks toe te voegen die je kan kopen met punten die je verdient in de game.

> ### Anoniem 2
> Misschien handig zijn om in de game stages toe te voegen dat het progressief moeilijker wordt

> ### Anoniem 3
> Zou de map eventueel groter maken, of de onderkant wat veranderen, ziet er momenteel een beetje apart uit.
> Verder ziet het er goed uit.

> ### Anoniem 4
> De game mist momenteel geluid, zou het iets interessanter maken.

> ### Anoniem 5
> Misschien wat meer game lore toevoegen, of een backstory.
> Ook leuk om wat meer enemies toe te voegen.

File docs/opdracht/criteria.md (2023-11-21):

# Criteria

Net als de opdracht van blok 1, is ook deze opdracht opgedeeld in een aantal criteria. Deze criteria zijn opgedeeld in kwaliteitscriteria en gedragscriteria. De kwaliteitscriteria zijn de criteria die je project moet bevatten, de gedragscriteria zijn de criteria die je gedrag beschrijven.

## Kwaliteitscriteria

Voor het bouwen van deze opdracht heb je 3 sprints de tijd. Aan het einde van die periode moet je applicatie aan een aantal verwachtingen voldoen. We noemen dit de kwaliteitscriteria. Voor dit blok zien de kwaliteitscriteria er als volgt uit:

| Cat | Nr | Kwaliteitscriteria | HBO-i model |
|-----|----|---|---|
| 1 | K1 | Je hebt (een groot deel van) de user stories afgerond. | G, S |
| 1 | K2 | Je hebt de behoeftes van de doelgroep onderzocht en gebruikt om zelf een aantal user stories te schrijven. | G-A |
| 1 | K3 | Je hebt de gebruikersinterface van jouw product aangepast door prototyping toe te passen. | G-A, G-O, G-R |
| 1 | K4 | Je hebt een testplan geschreven en gebruikt om een gebruikerstest uit te voeren. | G-R |
| 2 | K5 | Je hebt object georiënteerd geprogrammeerd en maakt gebruik van objectgeoriënteerde technieken zoals abstraction, inheritance en encapsulation. | S-O, S-R |
| 2 | K6 | Je hebt een genormaliseerde relationele database ontworpen en gebruikt om informatie uit je project in op te slaan, op te halen en te bewerken. | S-O, S-R |
| 2 | K7 | Je hebt je werk beschreven met behulp van UML-technieken. | S-R, S-MC |

## Gedragscriteria

Om een IT-project succesvol op te leveren, is het noodzakelijk dat je leert om je als een professional te gedragen. Je hebt hiervoor vaardigheden nodig, die we binnen het hbo professional skills noemen. Voor dit project dient je gedrag aan de volgende criteria te voldoen:

| Cat. | Nr | Gedragscriteria | HBO-i model |
|---|----|---|---|
| 3 | G1 | Je neemt verantwoordelijkheid voor je eigen handelen. Je aanvaardt consequenties van jouw gedrag. Je geeft op constructieve feedback aan medestudenten en ontvangt feedback. Je geeft aan hoe je die feedback gaat gebruiken. Je werkt resultaat gericht aan je opdracht of taak. Je hebt een actieve werkhouding. Je leert van en met elkaar en bent aanwezig op contactmomenten. Je herkent waar je leerbehoeftes zitten en stelt doelen op om deze te vervullen. Je reflecteert op je handelen en je evalueert je doelen.| PL-PO |
| 4 | G4 | Je werkt volgens (gegeven) kwaliteitsnormen. | TO-M |
| 4 | G5 | Je kan constructief samenwerken in een duo. | DI-P |
| 4 | G6 | Je gebruikt bronnen om antwoorden te vinden op een passende manier. | OP-O |
| 4 | G7 | Je kunt je doel door middel van een presentatie begrijpelijk overbrengen aan de doelgroep. | DI-C |
| 4 | G8 | Je schrijft gestructureerde en begrijpelijke documentatie. | DI-C |
| 4 | G10 | Je bent je bewust van de invloed die je uitoefent met jouw werk. | TO-E |

{{ mdocotion_header('https://images.unsplash.com/photo-1484480974693-6ca0a78fb36b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') }}

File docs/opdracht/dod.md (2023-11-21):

# Definition of Done

Binnen scrum dient iedere user story te voldoen aan een zogenaamde Definition of Done (DoD). Door het opstellen en aanhouden van een Definition Of Done, zorg je ervoor dat het werk wat je aflevert ook daadwerkelijk gebruikt kan worden. 

Als je een user story hebt afgebouwd zet je 'm in _verify_ en controleer je of deze voldoet aan de _Definition of Done_ (zie hieronder). Pas als dat in orde is kun je de user story op _Done_ zetten.

## DoD generiek

- Alle acceptatiecriteria zijn afgevinkt.
- Het werk is (technische) gedocumenteerd en relevant voor collega-ontwikkelaars.
- Het werk is geschreven in Standaardnederlands.
- Het werk staat in de Gitlab repository.
- Het werk is gereviewd door een peer.
- Het werk voldoet aan het Think-Make-Check (TMC) principe.
- De code is opgesteld volgens de HBO-ICT coding conventions.
- De code is handmatig functioneel getest op fouten.
- De code werkt zonder fouten bij normaal gebruik.
- De webapplicatie dient zowel op mobiele- als desktop-apparaten gebruikt te kunnen worden.

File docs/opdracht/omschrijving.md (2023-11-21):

# Opdracht omschrijving

## Context

Dit is het project voor Technische Informatica in blok 2, in het studiejaar 2023 - 2024. In het eerste blok heb je gewerkt aan een Climate Measuring Box om zelf metingen te verrichten en deze vervolgens te visualiseren op een webpagina. In dit blok ga je werken aan het project Game Controller, hiervoor maak je gebruik van de kennis die je in blok 1 hebt opgedaan en ga je aan de slag om nieuwe kennis op te doen.

Voor dit project ga je aan de slag met het bouwen van een website (je game console), het bouwen van een embedded systeem (je controller) en een database (voor de highscores).

## Opdracht

Op de open dag willen we studiekiezers, jongeren die een studiekeuze moeten maken, laten zien wat studenten HBO-ICT al kunnen maken in het begin van hun opleiding. Studiekiezers lopen rond en kunnen bij verschillende stands een kijkje nemen. 

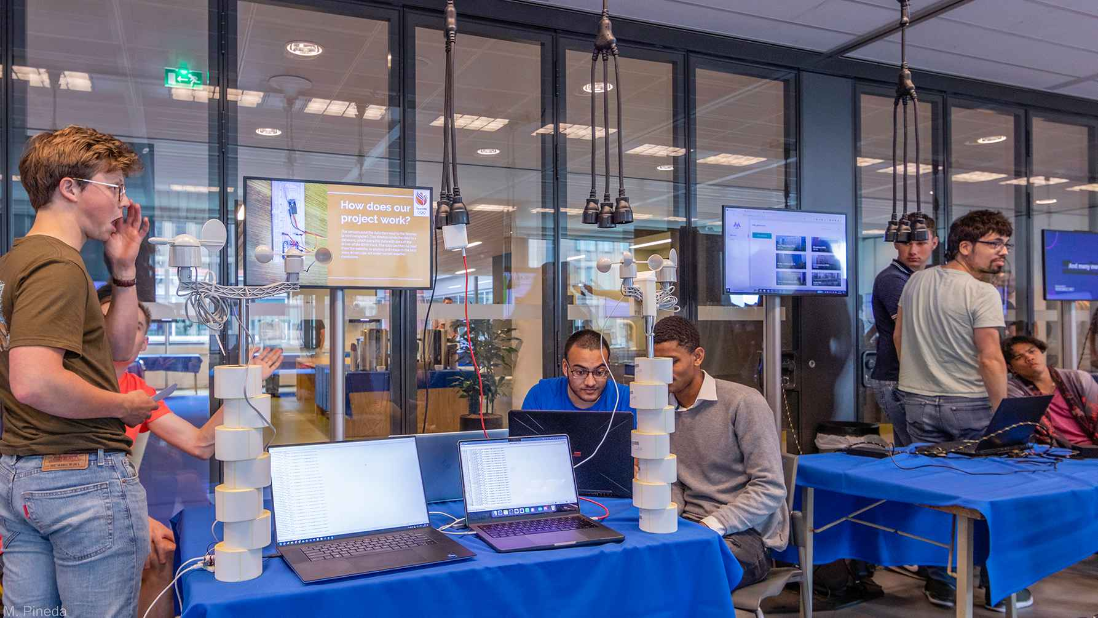
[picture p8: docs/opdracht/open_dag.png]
open_dag


Alleen kijken is niet genoeg, we willen ze ook iets laten doen. Daarom is de opdracht voor jullie:

> Maak een game die de studiekiezer makkelijk kan spelen op de open dag. Laat de studiekiezer de game spelen met je eigen, zelfgemaakte gamecontroller.

Stel je voor dat er op de 5e verdieping overal grote schermen staan waar draadloze gamecontrollers voor zijn gepositioneerd. Een bezoeker loopt er op af, pakt de controller en kan gelijk gaan spelen. Als de game afgelopen is kan de bezoeker zijn naam invullen en wordt de highscore opgeslagen in een database. De bezoeker kan thuis op een website de highscores bekijken.

Om dit voor elkaar te krijgen zullen de games makkelijk moeten kunnen worden klaargezet door het personeel dat op de open dag aanwezig is.

## Vereisten

### Het product

- De game moet makkelijk te bedienen en te begrijpen zijn voor de speler.
- De medewerkers van de open dag moeten de game makkelijk kunnen klaarzetten en opstarten.
- Na het spelen van de game moeten achievements en highscores worden opgeslagen in een database.
- De speler moet de achievements en highscores thuis kunnen bekijken op een webpagina.

!!! tip "Tip: Simpele Game Mechanics"

    Om de game simpel te houden zullen de input mogelijkheden beperkt moeten zijn. Gebruik zo min mogelijk knoppen. Om je te helpen bij het bedenken van de game mechanics, hieronder een lijst met mogelijke game mechanics.

    - Het drukken van een knop op een specifiek tijdstip.
    - Het drukken van een knop op een specifiek tijdsinterval.
    - Het drukken van een knop op een specifiek tijdsinterval, waarbij de interval steeds korter wordt.
    - Het drukken van een knop op een specifiek tijdsinterval, waarbij de interval steeds langer wordt.
    - Hoe verder je in het spel zit, hoe sneller je moet reageren.
    - Het indrukken van de knop en loslaten op een specifiek tijdstip.
        - Opladen; bijvoorbeeld krachtiger, harder, sneller, ...
        - Afvuren; bijvoorbeeld schieten, springen, ...
    - Het herhaarlijk indrukken van een knop.
        - Bijvoorbeeld om te rennen, springen, ...

## Techniek

- de game wordt gespeeld vanuit een webpagina
- de game is geprogrammeerd in JavaScript
- p5.js wordt gebruikt voor het tekenen van de game

{{ mdocotion_header('https://images.unsplash.com/photo-1586892477838-2b96e85e0f96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') }}

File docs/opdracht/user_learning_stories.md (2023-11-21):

# Overzicht userstories

## Als gebruiker wil ik de behaalde resultaten van het spel zien in de vorm van highscores zodat ik kan zien wat de hoogst behaalde scores zijn

### Issue Details

**Labels:** `Type::User Story`

#### Beschrijving

Niks is leuker dan de beste te zijn in een spel. Gun jouw gebruiker die ervaring door een overzicht van de 10 beste scores weer te geven.

??? note "Definitions of Done"

    #### Definitions of Done

    - [ ] Alle acceptatie criteria zijn behaald
    - [ ] Het werk is gedocumenteerd, zodat een teamlid hiermee verder kan
    - [ ] Het werk is geschreven in Standaardnederlands
    - [ ] Het werk staat op de gitlab repository
    - [ ] Het werk is gereviewd door een peer

    ##### Software specifiek

    - [ ] De code is opgesteld volgens de HBO-ICT code conventions
    - [ ] De code is handmatig functioneel getest op fouten
    - [ ] De code werkt zonder fouten bij normaal gebruik

#### Acceptatie criteria

- [ ] De score wordt tijdens het spelen periodiek opgeslagen in de database.
- [ ] Aan het einde van het spel wordt de score weergegeven naast de 10 eerder behaalde high scores van alle spelers van het spel.
- [ ] Alleen de 10 hoogst behaalde scores worden weergegeven in het overzicht.
- [ ] De scores worden voor aanvang van het spel weergegeven in een overzicht.

---

## Als gebruiker wil ik mijn naam kunnen achterlaten bij mijn score zodat in het score overzicht te zien is dat de score door mij gehaald is

### Issue Details

**Labels:** `Type::User Story`

#### Beschrijving

Als je een high score heb behaald, dan wil je wel dat iedereen weet dat jij dat was. Geef dus ook de gebruiker van jouw spel de mogelijkheid om zijn ego te strelen.

??? note "Definitions of Done"

    #### Definitions of Done

    - [ ] Alle acceptatie criteria zijn behaald
    - [ ] Het werk is gedocumenteerd, zodat een teamlid hiermee verder kan
    - [ ] Het werk is geschreven in Standaardnederlands
    - [ ] Het werk staat op de gitlab repository
    - [ ] Het werk is gereviewd door een peer

    ##### Software specifiek

    - [ ] De code is opgesteld volgens de HBO-ICT code conventions
    - [ ] De code is handmatig functioneel getest op fouten
    - [ ] De code werkt zonder fouten bij normaal gebruik

#### Acceptatie criteria

- [ ] Aan het einde van het spel wordt de score weergegeven naast de eerder behaalde scores van de spelers van het spel.
- [ ] Alleen de hoogst behaalde score van de speler wordt weergegeven in het overzicht, maar alle behaalde scores worden bewaard.
- [ ] De speler kan een naam koppelen aan de score aan het einde van het spel door een naam in te voeren.
- [ ] Voor het invoeren van de naam zijn minimaal 1 knop nodig voor het wisselen van characters en 1 knop voor de volgende character.
- [ ] Zowel de controller als het toetsenbord kunnen gebruikt worden om de naam in te voeren.
- [ ] Alleen ASCII characters kunnen ingevoerd worden.

---

## Als gebruiker wil ik de 'game console' op de website volledig bedienen met een controller zodat ik niet hoef te wisselen tussen controller en laptop toetsenbord

### Issue Details

#### Labels:** `Type::User Stor**Beschrijving**  

??? note "Definitions of Done"

    #### Definitions of Done

    - [ ] Alle acceptatie criteria zijn behaald
    - [ ] Het werk is gedocumenteerd, zodat een teamlid hiermee verder kan
    - [ ] Het werk is geschreven in Standaardnederlands
    - [ ] Het werk staat op de gitlab repository
    - [ ] Het werk is gereviewd door een peer

    ##### Software specifiek

    - [ ] De code is opgesteld volgens de HBO-ICT code conventions
    - [ ] De code is handmatig functioneel getest op fouten
    - [ ] De code werkt zonder fouten bij normaal gebruik

#### Acceptatie criteria

- [ ] ...
- [ ] ...
- [ ] ...

---

## Als gebruiker wil ik op een website een virtuele 'game console' ervaring waardoor ik echt het gevoel krijg dat ik een spel ga opstarten

### Issue Details

**Labels:** `Type::User Story`

#### Beschrijving

Voor een goede gebruikerservaring van het spelen van een spel is het uiterlijk en gedrag van de applicatie van grote invloed. Omdat we een game gaan maken met controller, willen we ook echt dat game console gevoel geven. Het is niet de bedoeling dat de gebruiker het gevoel heeft op een website te zitten. Het gevoel dat dit een game console is moet zowel in uiterlijk als gedrag gerealiseerd worden.

??? note "Definitions of Done"

    #### Definitions of Done

    - [ ] Alle acceptatie criteria zijn behaald
    - [ ] Het werk is gedocumenteerd, zodat een teamlid hiermee verder kan
    - [ ] Het werk is geschreven in Standaardnederlands
    - [ ] Het werk staat op de gitlab repository
    - [ ] Het werk is gereviewd door een peer

    ##### Software specifiek

    - [ ] De code is opgesteld volgens de HBO-ICT code conventions
    - [ ] De code is handmatig functioneel getest op fouten
    - [ ] De code werkt zonder fouten bij normaal gebruik

#### Acceptatie criteria

- [ ] De virtuele game console heeft de kleurgebruik, tekst type, tekst grote en visuele inrichting die past bij game consoles.
- [ ] De virtuele game console kan fullscreen gedraaid worden, zodat alle webbrowser aspecten verborgen zijn.
- [ ] Het gedrag van de game console is zodanig dat de gebruiker het idee heeft dat het spel geladen wordt, en er ook andere spellen geladen zouden kunnen worden.
- [ ] Vormgeven is zo veel mogelijk verzorgt middels CSS. Overige componenten zijn verzorgt via HTML Canvas en JavaScript.
- [ ] (Nice to have) De vormgeving is dusdanig opgezet dat er van type virtuele game console ervaring (bijv. tussen retro 8-bit en next-gen) gewisseld kan worden naar smaak van de gebruiker.

---

## Als gebruiker wil ik als eerste een uitleg-scherm krijgen bij het opstarten van een spel zodat ik instructies krijg over hoe het spel gespeeld moet worden

### Issue Details

**Labels:** `Type::User Story`

#### Beschrijving

Je spel moet out-of-the-box te spelen zijn. Er is dus geen handleiding nodig, alle uitleg die het spel nodig heeft in gebruik en speldoel moet het spel zelf geven.

??? note "Definitions of Done"

    #### Definitions of Done

    - [ ] Alle acceptatie criteria zijn behaald
    - [ ] Het werk is gedocumenteerd, zodat een teamlid hiermee verder kan
    - [ ] Het werk is geschreven in Standaardnederlands
    - [ ] Het werk staat op de gitlab repository
    - [ ] Het werk is gereviewd door een peer

    ##### Software specifiek

    - [ ] De code is opgesteld volgens de HBO-ICT code conventions
    - [ ] De code is handmatig functioneel getest op fouten
    - [ ] De code werkt zonder fouten bij normaal gebruik

#### Acceptatie criteria

- [ ] Bij het opstarten van het spel is er een uitleg over hoe je het spel speelt.
- [ ] De uitleg beschrijft hoe je het spel bedient met de controller.
- [ ] De uitleg beschrijft hoe je het spel bedient met het toetsenbord.
- [ ] De uitleg beschrijft wat het doel is van het spel.
- [ ] De uitleg is niet alleen tekst, maar ook visueel.
- [ ] De uitleg is op een later moment ook oproepbaar.
- [ ] De uitleg kan met één druk op de knop weggehaald worden.
- [ ] De uitleg past bij de vormgeving van het spel.
- [ ] Wanneer de speler af is en een nieuw spel start wordt de uitleg NIET weer opnieuw gegeven.

---

## Als gebruiker wil ik het spel kunnen spelen door middel van één knop zodat je minimaal één van de game mechanics kan toepassen

### Issue Details

**Labels:** `Type::User Story`

#### Beschrijving

Een goed leuk spel wat makkelijk te spelen is heeft niet teveel knoppen en geen moeilijke knoppen combinaties. Ook dit spel moet simpel zijn in gebruikt. Beperk de game dynamics zodanig dat er maar één knop nodig is om een standaard actie te voeren. Een goed voorbeeld is de [Google Chrome Dino](https://chromedino.com/mario/) waarbij met één knop de dino bestuurd wordt. Maar er is een heel genre [arcade achtige games](https://www.crazygames.com/t/one-button) waarbij maar één knop nodig is.

??? note "Definitions of Done"

    #### Definitions of Done

    - [ ] Alle acceptatie criteria zijn behaald
    - [ ] Het werk is gedocumenteerd, zodat een teamlid hiermee verder kan
    - [ ] Het werk is geschreven in Standaardnederlands
    - [ ] Het werk staat op de gitlab repository
    - [ ] Het werk is gereviewd door een peer

    ##### Software specifiek

    - [ ] De code is opgesteld volgens de HBO-ICT code conventions
    - [ ] De code is handmatig functioneel getest op fouten
    - [ ] De code werkt zonder fouten bij normaal gebruik

#### Acceptatie criteria

- [ ] Een toets van het toetsenbord kan gebruikt worden voor de basis actie.
- [ ] De toetsen van het toetsenbord die gebruik worden zijn logische voor de interactie. (bijvoorbeeld pijltjes toetsen voor richting, spatie voor springen)
- [ ] Er is een maximum van 8 toetsen nodig voor de totale interactie van het spel.
- [ ] Er zijn geen toetsencombinaties nodig voor standaard interactie.
- [ ] De functionaliteit van de applicatie is los gekoppeld aan de toetsen.
- [ ] De keuze van toetsen voor het toetsenbord zijn makkelijk te veranderen in de applicatie

---

## Als gebruiker wil ik dat mijn invoer op de controller direct invloed uitoefent op het spel zodat ik 'low input lag'-spellen kan spelen

### Issue Details

**Labels:** `Type::User Story`

#### Beschrijving

Een snelle 'low input lag' zorgt voor een goede spelervaring. Als een reactie van het indrukken van een knop onder de 20ms is, ervaren we dit als direct. Als de reactie tever van deze reactietijd zit, bijvoorbeeld 100ms, dan ervaren we dat als lag. Bij nog tragere reactie tijd gaan we vermoeden dat het systeem vastloopt en haken we af. Nog erger reacties boven de 100ms [beïnvloeden een goede gaming experience](http://www.cse.yorku.ca/~andriyp/papers/p109-pavlovych.pdf). Belangrijk dus dat we zorgen dat de reactie snelheid van het systeem op de controller snel is en dicht bij die 20ms zit.

??? note "Definitions of Done"

    #### Definitions of Done

    - [ ] Alle acceptatie criteria zijn behaald
    - [ ] Het werk is gedocumenteerd, zodat een teamlid hiermee verder kan
    - [ ] Het werk is geschreven in Standaardnederlands
    - [ ] Het werk staat op de gitlab repository
    - [ ] Het werk is gereviewd door een peer

    ##### Software specifiek

    - [ ] De code is opgesteld volgens de HBO-ICT code conventions
    - [ ] De code is handmatig functioneel getest op fouten
    - [ ] De code werkt zonder fouten bij normaal gebruik

#### Acceptatie criteria

- [ ] Idealiter is binnen minimaal 20ms en maximaal 100ms) voor de gebruiker een reactie zichtbaar op de virtual console na het indrukken van een knop.
- [ ] De microcontroller registeerd minimaal binnen 100ms dat een knop is ingedrukt.
- [ ] De microcontroller mist geen ingedrukte knoppen.
- [ ] De microcontroller verstuurd iedere ingedrukte knop naar de virtual console.
- [ ] De microcontroller registeerd los dat een knop is ingedrukt (pressed) en een knop is losgelaten(released).
- [ ] De microcontroller moet minimaal via een seriële vrrbinding contact hebben met de virtual console.
- [ ] (Nice to have) De microcontroller heeft via een draadloze verbinding contact met de virtual console.
- [ ] De oplossing is schematisch vastgelegd.

---

## Als gebruiker wil tijdens het spelen mijn score 'live' zien zodat ik weet wat de progressie is die ik aan het maken ben tijdens het spelen

### Issue Details

**Labels:** `Type::User Story`

#### Beschrijving

Het zien van de voortgang in een spel helpt een gebruiker om het overzicht te houden, maar kan ook bijdragen aan het competitie aspect. Hoe gaaf is het als het publiek ziet dat jij de hoogste score aan het behalen bent!

??? note "Definitions of Done"

    #### Definitions of Done

    - [ ] Alle acceptatie criteria zijn behaald
    - [ ] Het werk is gedocumenteerd, zodat een teamlid hiermee verder kan
    - [ ] Het werk is geschreven in Standaardnederlands
    - [ ] Het werk staat op de gitlab repository
    - [ ] Het werk is gereviewd door een peer

    ##### Software specifiek

    - [ ] De code is opgesteld volgens de HBO-ICT code conventions
    - [ ] De code is handmatig functioneel getest op fouten
    - [ ] De code werkt zonder fouten bij normaal gebruik

#### Acceptatie criteria

- [ ] De score van de gebruiker wordt bijgehouden vanaf het moment dat het spel gespeeld wordt.
- [ ] De score wordt weergegeven op het scherm, zodat de gebruiker het kan zien, maar de score niet het spellen belemmerd.
- [ ] De score loopt op naarmate de speler verder komt in het spel.

---

## Als gebruiker wil ik dat mijn spelstatus wordt opgeslagen in een database, zodat ik op een later moment het spel kan hervatten

### Issue Details

**Labels:** `Type::User Story`

#### Beschrijving

Niks is vervelender dan te moeten stoppen met een spel dat je leuk vindt. Hoe fijn is het dan wanneer je terug komt, je verder kan gaan waar je gebleven bent. Kortom je spel moet de gebruiker de mogelijkheid geven om het spel op te slaan en op een later tijdstip te hervatten.

??? note "Definitions of Done"

    #### Definitions of Done

    - [ ] Alle acceptatie criteria zijn behaald
    - [ ] Het werk is gedocumenteerd, zodat een teamlid hiermee verder kan
    - [ ] Het werk is geschreven in Standaardnederlands
    - [ ] Het werk staat op de gitlab repository
    - [ ] Het werk is gereviewd door een peer

    ##### Software specifiek

    - [ ] De code is opgesteld volgens de HBO-ICT code conventions
    - [ ] De code is handmatig functioneel getest op fouten
    - [ ] De code werkt zonder fouten bij normaal gebruik

#### Acceptatie criteria

- [ ] Een spelstatus bestaat uit minimaal de positie van de speler in het spel en de tot dan toe behaalde score. Afhankelijk van het spel kan ook tijd of andere variabelen meegenomen worden in het spel.
- [ ] De applicatie heeft een functie die de spelstatus van de gebruiker bijhoud.
- [ ] De applicatie heeft een functie die de spelstatus opslaat in de database gekoppeld aan de gebruiker.
- [ ] De gebruiker kan een minimum van 1 en een maximum van 3 spelstatussen opslaan.
- [ ] Wanneer 3 spelstatussen zijn opgeslagen kan de gebruiker kiezen welke wordt overschreven.

---

## Learning story: Ik wil aantonen dat ik betrouwbare bronnen gebruik

### Issue Details

**Labels:** `G10:: Invloed`<br>`G6::Bronnen`<br>`K4::Gebruikerstest`<br>`Type::Learning Story`

De informatie die je gebruikt en opschrijft is altijd gebaseerd op betrouwbare bronnen. Bronnen heb je nodig om je te verantwoorden. Ook laat brongebruik zien dat je je hebt ingelezen in het onderwerp en dat je je bewust bent van de bestaande perspectieven en theorieën.  

Elke bron die je gebruikt moet je duidelijk vermelden. Het is daarom belangrijk alle gegevens van de bronnen die je gebruikt goed bij te houden. Zorg er ook voor dat je zelf nog weet welke informatie uit welke bron komt en op welke pagina die informatie bijvoorbeeld stond.

**Wat moet ik kunnen?**

Ik weet hoe ik betrouwbare informatie kan zoeken. Ik kan bronnen beoordelen op hun betrouwbaarheid en kwaliteit.

**Hoe leer ik dat?**

- [ ] [Knowledge base: Bronnen zoeken]( https://knowledgebase.hbo-ict-hva.nl/2_professional_skills/onderzoekend_probleemoplossen/0_onderzoekend_probleemoplossen/)

---

## Learning Story: Ik kan een relevant leerdoel formuleren en daarop reflecteren

### Issue Details

**Labels:** `G1::Persoonlijke ontwikkeling`<br>`Type::Learning Story`

In het vorige blok is de focus gelegd op resultaatgericht werken, verantwoordelijkheid nemen voor je handelen, feedback geven, een actieve werkhouding hebben en actief deelnemen. In dit blok wordt dit ook van je verwacht, maar komt er een belangrijk punt bij. Het opstellen van leerdoelen voor jezelf.

Leerdoelen formuleren is een belangrijke vaardigheid die je helpt om regie te nemen over je leerproces. Gedurende je hele loopbaan is het belangrijk om jezelf te blijven ontwikkelen. Het is belangrijk dat jij zelf je  leerdoelen bewust bepaalt en dat ze haalbaar zijn. Je moet helder krijgen welke leerdoelen op dat moment relevant zijn en hoe je daarmee aan de slag wilt. Het is de bedoeling dat je leert haalbare leerdoelen te formuleren die aansluiten bij wat er op dat moment van jou wordt gevraagd op het gebied van persoonlijke en professionele vaardigheden.  

**Wat moet ik kunnen?**

Je weet wat het verschil is tussen een leerdoel en een resultaat, je kunt uitleggen welke vaardigheden er van jou worden gevraagd en wat dat betekent voor jouw ontwikkeling. Ook kun je een keuze maken voor leerdoelen die je ook echt verder helpen en waar je voor wilt gaan. Je kunt je leerdoelen specifiek beschrijven en concreet maken en kent verschillende methodieken die je helpen om je leerdoelen concreet te maken. Die leerdoelen kun je vervolgens verwoorden in een learning story.

**Hoe leer ik dat?**

- [ ] [Knowledge base: SMART-leerdoelen](https://knowledgebase.hbo-ict-hva.nl/2_professional_skills/persoonlijk_leiderschap/persoonlijke_ontwikkeling/SMART_leerdoelen/)
- [ ] [Knowledge base: Learning story schrijven](https://knowledgebase.hbo-ict-hva.nl/2_professional_skills/persoonlijk_leiderschap/ondernemend_zijn/learning_story_schrijven/)
- [ ] Coachingsgesprek met de docent waarin je leerdoel(en) afstemt

---

## Learning story: Ik kan aantonen dat mijn product digitaal toegankelijk is

### Issue Details

**Labels:** `G10:: Invloed`<br>`K2::User Stories opstellen`<br>`K3::Prototyping`<br>`K4::Gebruikerstest`<br>`Type::Learning Story`

**1. Inleiding**  
Tijdens en na deze opleiding werk je aan opdrachten voor een bedrijf of organisatie. Wat jij doet en waar je aan werkt heeft consequenties voor het bedrijf, maar ook voor de rest van de wereld. Hierbij kun je denken aan maatschappelijke en ethische kwesties. Je oriënteert je op deze kwesties en maakt op basis daarvan bewuste, goed afgewogen keuzes. Je houdt rekening met maatschappelijke gevolgen en duurzaamheid van een oplossing. Tijdens dit project richt je je op de digitale toegankelijkheid van jouw product.

**2. Wat moet ik leren?**  
Je kunt uitleggen, aan de hand van een advies, op welke manier je bij het werken aan je opdracht rekening hebt gehouden met verschillende gebruikers, bijvoorbeeld door het implementeren van een inclusief ontwerp dat digitaal toegankelijk is.

- [ ] Onderzoek doen [naar digitale toegankelijkheid](https://kennisbank.digitoegankelijk.nl/)
- [ ] Een [advies schrijven](https://www.taalwinkel.nl/tekstsoorten/adviesrapport/adviesrapport.html)

**3. Hoe leer ik dit?**  
[digitale toegankelijkheid](https://kennisbank.digitoegankelijk.nl/)

[W3C Web Accessibility guidelines (WAI) en Persona's](https://www.w3.org/WAI/redesign/personas)

[advies schrijven](https://www.taalwinkel.nl/tekstsoorten/adviesrapport/adviesrapport.html)

**4. Aan welke Kwaliteitscriteria of Gedragscriteria is dit gerelateerd?**
G8 Je schrijft gestructureerde en begrijpelijke documentatie.  
G10 Je bent je bewust van de invloed die je uitoefent met jouw werk

---

## Learning story: Ik kan een professionele presentatie maken en geven

### Issue Details

**Labels:** `G7::Presentatie`<br>`K3::Prototyping`<br>`Type::Learning Story`

Een presentatie is een heel specifiek communicatiemiddel. Als IT-professional zul je op momenten jouw ideeën of oplossingen op een begrijpelijke manier moeten overbrengen op anderen. Het kan een belangrijk moment met je opdrachtgever zijn, waarin je diens vertrouwen in jou kunt bevestigen of versterken. Maar het kan bijvoorbeeld ook een nuttig middel zijn om kennis over te dragen aan collega’s.  Een groot deel van de presentaties binnen de IT-sector hebben echter het doel om samenwerking te bevorderen. Als een organisatie met de  Scrum-methode werkt, vindt er aan het einde van elke sprint een Sprint Review plaats. Dat is een moment waarop alle betrokkenen bij het project (de stakeholders) op de hoogte worden gebracht van de voortgang.  

**Wat moet ik kunnen?**

Je kunt 5-10 minuten presenteren op een duidelijke, semi-formele, overtuigende wijze. Je kunt standaard presentatietechnieken toepassen. Je presenteert en houdt rekening met doel en de doelgroep van je presentatie. Ook houd je rekening met tempo, intonatie, volume, houding, non-verbale communicatie, structuur en opbouw. Je presentatie heeft een pakkende inleiding en uitsmijter.

**Hoe leer ik dat?**

- [ ] [Knowledge base: Presenteren](https://knowledgebase.hbo-ict-hva.nl/2_professional_skills/doelgericht_interacteren/0_doelgericht_interacteren/)

---

## Learning Story: Ik wil leren hoe ik een user story schrijf op basis van de wensen van de gebruiker

### Issue Details

**Labels:** `K2::User Stories opstellen`<br>`Type::Learning Story`

**1. Inleiding**  

Een user story is een beschrijving van een functie van een product.
Aangezien deze functie door iemand gaat worden gebruikt, wordt deze altijd geschreven vanuit het perspectief van een gebruiker. Het volgt de vaste formule:

*Als [gebruiker] wil ik [functie] zodat ik [reden/doel van functie]*.

Bijvoorbeeld:

- *Als student wil ik mijn rooster kunnen zien, zodat ik weet waar en wanneer ik op de campus moet zijn*.

Daardoor weet je zeker dat je niet zomaar iets aan het bouwen bent, maar dat jouw functie daadwerkelijk gebruikt gaat worden en iets toevoegt aan de ervaring van een gebruiker.
Het helpt te begrijpen wie de gebruikers zijn, wat ze nodig hebben en waarom ze jouw product kiezen.

Daarnaast is het een belangrijk communicatiemiddel, zodat alle betrokken partijen weten wat er precies gebouwd gaat worden. Het is dus belangrijk om zo specifiek mogelijk te zijn over wanneer de functie *af* is.

**2. Wat moet ik leren?**  

- [ ] Ik wil begrijpen wat de behoeften en doelen van mijn gebruiker zijn zodat ik deze kan vertalen naar functionaliteiten in mijn product (zie Learning Story #9).
- [ ] Ik wil voor elke functionaliteit een User Story schrijven met een concrete titel, Definitions of Done en acceptatiecriteria, zodat ik en de betrokken stakeholders weten wanneer een functionaliteit af is.
- [ ] Ik wil gebruikmaken van de industriestandaard om User Stories te schrijven zoals: *als een \[gebruiker/rol\] wil ik \[actie/doel\], zodat \[reden van functionaliteit\]*.
- [ ] Ik wil nadenken over de waarde die een functionaliteit bijdraagt aan het eindproduct.
- [ ] Ik wil mijn User Stories kunnen toevoegen aan het juiste issue board.
- [ ] Ik wil feedback ontvangen op mijn User Stories voordat ik begin met bouwen.

**3. Hoe leer ik dit?**  
Knowledge Base: [User Story](https://knowledgebase.hbo-ict-hva.nl/2_professional_skills/toekomstgericht_organiseren/managen/user_story/)  
en
[Definitions of Done en Acceptatiecriteria](https://agilescrumgroup.nl/wat-is-definition-of-done/)
<https://agilepainrelief.com/blog/definition-of-done-user-stories-acceptance-criteria.html>

<https://www.scrum.org/resources/blog/done-understanding-definition-done>

<https://agilescrumgroup.nl/wat-is-definition-of-done/>

**4. Aan welke Gedragscriteria is dit gerelateerd?**  

- K2: Je hebt de behoeftes van de doelgroep onderzocht en gebruikt om zelf een aantal user stories te schrijven.

---

## Learning Story: Ik wil leren hoe ik de behoeftes van de gebruiker vastleg in een gebruikersonderzoek

### Issue Details

**Labels:** `K2::User Stories opstellen`<br>`K4::Gebruikerstest`<br>`Type::Learning Story`

Een goed product verkoopt zichzelf - wie deze uitspraak heeft bedacht heeft nooit rekening gehouden met het digitale tijdperk. Je zal keuzes moeten maken over welke functies je wel wel en niet gaat bouwen. Je zal daarbij rekening moeten houden met en prioriteit geven aan de behoeften van potentiële gebruikers.

Daarom ligt aan de basis van bijna elke applicatie tegenwoordig een gebruikersonderzoek ten grondslag. Hierin beschrijf je wie je gebruikers zijn en wat ze nodig hebben om hun ervaring beter te maken (zowel in functionaliteit als in design en interactie).

Een veel voorkomend proces om gebruikers onderzoek door je sprints heen te blijven doen is de Think, Make, Check cyclus waarbij je in de Think fase onderzoek doet naar gebruikersbehoeftes, in de Make fase prototypes uitwerkt en in de Check fase kijkt of je ideeën ook echt werkbaar zijn voor je gebruikers.

**Wat moet ik leren?**

- [ ] Ik wil gebruik maken van een iteratieve manier om gebruikersonderzoek te doen met behulp van de think, make, check cyclus

TMC 1

- [ ] **THINK** - Ik wil een Mindmap maken over mijn gebruikers en hun wensen.
- [ ] **THINK** - Ik wil een Task Flow leren maken, die ik kan omzetten in een wireflow.
- [ ] **MAKE** - Ik wil functionaliteiten en inzichten beschrijven aan de hand van user stories (Zie learning story over K2)
- [ ] **MAKE** - Ik wil lo-fi prototype maken in de vorm van een schets (Zie learning story over K3 Prototyping)
- [ ] **CHECK** - Ik wil aan de hand van lo-fi prototypes (Zie learning story over K3 Prototyping) gebruikerservaring testen in een Guerilla Test
- [ ] Ik wil functionaliteiten en inzichten beschrijven aan de hand van user stories (Zie learnign story over K2)

TMC 2

- [ ] **THINK** - Ik wil inspiratie opdoen van vergelijkbare producten door een Inspiratie Analyse uit te voeren.
- [ ] **MAKE** - Ik wil een interactief prototype maken (Zie learning story over K3 Prototyping)
- [ ] **CHECK** - Ik wil aan de hand van med-fi prototypes (Zie learning story over K3 Prototyping) gebruikerservaring testen in een Guerilla Test
- [ ] Ik wil functionaliteiten en inzichten beschrijven aan de hand van user stories (Zie learning story over K2)

TMC 3

- [ ] **THINK** - Ik wil testkaarten gebruiken om mijn hypotheses te valideren zonder dat ik bevooroordeeld ben of leidende vragen stel
- [ ] **MAKE** - Ik wil een med-fi of hi-fi prototype hebben die ik kan testen
- [ ] **CHECK** - Ik wil een gebruikerstest uitvoeren en mijn inzichten documenteren in leerkaarten
- [ ] Ik wil functionaliteiten en inzichten beschrijven aan de hand van user stories (Zie learning story over K2)

**Hoe moet ik dat leren?**

- Think, Make, Check cyclus

**Think**

- Mindmap
- Task flow
  - Zie ook deze youtube video <https://www.youtube.com/watch?v=npMv06oJJrM>
  - <https://www.usersknow.com/blog/2020/6/4/how-to-build-a-task-flow>
- Inspiratie analyse

**Make**

- User stories (Zie learning story over K2)
- Prototypes (Zie learning story over K3 Prototyping)

**Check**

- Gebruikerstest
  - Testkaarten
  - Leerkaarten
  - Guerilla Test <https://www.usertesting.com/blog/what-is-guerrilla-testing>

**4. Aan welke Kwaliteitscriteria of Gedragscriteria is dit gerelateerd?**

- K2: Je hebt de behoeftes van de doelgroep onderzocht en gebruikt om zelf een aantal user stories te schrijven.
- K3: Je hebt de gebruikersinterface van jouw product aangepast door prototyping toe te passen.
- K4: Je hebt een testplan geschreven en gebruikt om een gebruikerstest uit te voeren
- G6: Je gebruikt bronnen om antwoorden te vinden op een passende manier.
- G8: Je schrijft gestructureerde en begrijpelijke documentatie

---

## Learning Story: Ik wil leren hoe ik mijn project beschrijf met de Unified Modeling Language

### Issue Details

**Labels:** `K7::UML`<br>`Type::Learning Story`

**1. Inleiding**

De Unified Modeling Language, afgekort UML, is een modelleertaal waarmee je een visueel ontwerp kunt maken van je project. Het modelleren vindt plaats op basis van universele afspraken, zodat ieder project op dezelfde wijze wordt vastgelegd. Het UML-diagram gebruik je als houvast bij het werken aan je project, omdat in het UML staat beschreven wat objecten wel (en niet!) mogen, en hoe ze met elkaar samenwerken. Verder doet het dienst als technische documentatie, zodat andere mensen bijvoorbeeld onderhoud uit kunnen voeren aan een bepaald onderdeel van het project of iets nieuws kunnen toevoegen.

**2. Wat moet ik leren?**

Met UML kun je verschillende diagrammen maken. Binnen dit blok worden de volgende diagrammen gebruikt:

- [ ] [Use case diagram](https://en.wikipedia.org/wiki/Use_case_diagram). Hiermee kun je de mogelijke interacties die een gebruiker met een systeem kan aangaan beschrijven.
- [ ] [Class diagram](https://en.wikipedia.org/wiki/Class_diagram). Hiermee kun je classes modelleren voor een systeem.
- [ ] [Object diagram](https://en.wikipedia.org/wiki/Object_diagram). Hiermee kun je een momentopname maken van een object of objecten (instanties van class diagrammen) en hun data binnen een systeem.
- [ ] [State diagram](https://en.wikipedia.org/wiki/State_diagram). Hiermee kun je het gedrag van een systeem beschrijven.

**3. Hoe leer ik dit?**

- [ ] Knowledgebase: UML, class diagram, object diagram, use case diagram, state diagram.
- [ ] Handige tools om UML-diagrammen mee te maken: [UMLET](https://www.umlet.com/) en [Mermaid](https://knowledgebase.hbo-ict-hva.nl/1_beroepstaken/software/realiseren/talen/declaratief/markdown/mermaid_diagrammen/)

**4. Aan welke kwaliteits- en/of gedragscriteria is dit gerelateerd?**  
TODO: GEDRAGSCRITERIA

---

## Learning Story: Ik wil leren hoe ik de basisconcepten van objectgeoriënteerd programmeren toepas

### Issue Details

**Labels:** `K5::OOP`<br>`Type::Learning Story`

**1. Inleiding**

In het project tijdens blok 1 heb je vooral code geschreven die door de computer van boven naar beneden, regel voor regel wordt uitgevoerd. Dit noemen we ook wel *procedureel programmeren*.
Wellicht heb je gemerkt dat het best wel wat moeite kost om je code op een overzichtelijke manier te structureren. Waarschijnlijk heb je meerdere bestanden gebruikt om bepaalde soorten code te groeperen. Denk bijvoorbeeld aan een bestand waarin je alleen de inlogprocedure hebt opgenomen of een bestand waarin code zit voor het werken met de database van je applicatie. Hoe meer code je toevoegt aan je applicatie, hoe meer je moet nadenken over het structureren ervan. Je kunt zelfs een punt bereiken waarop je code minder overzichtelijk wordt en het onderhouden ervan meer tijd gaat kosten. Dit is een probleem waar al lang geleden prachtige oplossingen voor zijn bedacht. Een van die oplossingen is *object georiënteerd programmeren*, afgekort OOP (*Object Oriented Programming*).

Met object georiënteerd programmeren vertaal je de 'echte wereld' naar objecten. Objecten zijn dingen. Bijvoorbeeld een tafel, een stoel, een persoon, een dier, een adres, etc. Zo'n object bevat eigenschappen en gedrag. Feitelijk is een object dus een container waarin de eigenschappen en het gedrag zijn vastgelegd van het betreffende object. De beschrijving van de eigenschappen en het gedrag worden beschreven in een zogenaamde *class*. Een *class* is daarmee een blauwdruk van een object.

Als voorbeeld nemen we het object Hond. De eigenschappen van een hond kunnen zijn: kleur, gewicht, gevaarlijk, gechipt, etc. De gedragingen die bij een hond horen kunnen zijn: blaft, bijt, eet, slaapt, etc.

In je project ga je UML gebruiken (zie learning story over UML). De class in bovenstaand voorbeeld kan er in UML als volgt uitzien:

``` mermaid
classDiagram
    
    class Hond{
        -string kleur
        -int gewicht
        -boolean isGevaarlijk
        -boolean isGechipt
        +blaft()
        +bijt()
        +eet()
        +slaapt()
    }
```

In bovenstaand ontwerp zie je dat het class diagram in drie lagen is verdeeld. In de bovenste laag staat de naam van de class, in de middelste laag staan de eigenschappen van de class (attributen) en in de onderste laag staat het gedrag van de class (methodes).

Door te denken in objecten kun je de code van je programma op een logische manier structureren waardoor het efficiënter en beter herbruikbaar wordt.

**2. Wat moet ik leren?**

- [ ] beschrijven van een class
- [ ] begrip van scope
- [ ] scheiden van verantwoordelijkheden
- [ ] werken met constructor(s)
- [ ] gebruik maken van je class m.b.v. objecten

**3. Hoe leer ik dit?**

- [ ] Python: Intro to Python for Computer Science and Data Science, hoofdstuk 10. In te zien via de [O'Reilly database](https://lib.hva.nl/permalink/31UKB_UAM2_INST/ooc2dr/alma9939149327405132)
- [ ] Knowledgebase: basisconcepten OOP en/of
- [ ] Weblinks naar videocourses, boeken, websites over dit onderwerp.

---

## Learning Story: Ik wil leren hoe ik prototyping gebruik om de gebruikersinterface van mijn product vorm te geven

### Issue Details

**Labels:** `K3::Prototyping`<br>`Type::Learning Story`

Voordat je iets kan maken moet je eerst nadenken over wat het eindresultaat gaat zijn. Dit geldt voor alles in het leven: van back-end software implementaties tot prachtige user interfaces. Een digitale gebruikersinterface als een website, webapplicatie of smartphone applicatie maak je niet uit het niets.

Hiervoor bedenkt je eerst wat je gaat maken, hoe zich dat moet gedragen en hoe dat eruit moet zien. Met prototyping technieken als task flows en wireflows werk je eerst de ideeen uit tot een concept, voordat je ze vertaalt naar code. Pas wanneer je tevreden bent, en de ontwerpen volledig aansluiten op de gebruikersbehoeften, maak je de stap naar de daadwerkelijke implementatie. Zo voorkom je onnodig programmeerwerk.

**Wat moet ik leren?**

- [ ] Ik wil mijn task flow uitwerken in een lo-fi schets van een wireflow, op papier
- [ ] Ik wil nog een iteratie doen op mijn lo-fi schets door een wireflow te maken in Figma
- [ ] Ik wil de prototypes die ik maak gebruiken in de check fase van mijn TMC cyclus om inzichten te vergaren over de behoeftes van mijn gebruikers

**Hoe moet ik dat leren?**

- Prototypes
- Schetsen
- Wireflows
- Think, Make, Check cyclus

Extra informatie:

- [Wireframes Knowledgebase](https://knowledgebase.hbo-ict-hva.nl/1_beroepstaken/gebruikers_interactie/ontwerpen/wireframes/)
- [Wireframes Digital Society School](https://toolkits.dss.cloud/design/method-card/wireframes-2/)

Boek: [UX for the Web, Hoofdstuk "Creating wireframes and interactive prototypes" met name sectie "Creating a wireframe"](https://lib.hva.nl/discovery/fulldisplay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,contains,wireframe%20ux&offset=0)

**4. Aan welke Kwaliteitscriteria of Gedragscriteria is dit gerelateerd?**\
K3. Je hebt de gebruikersinterface van jouw product aangepast door prototyping toe te passen

---

## Learning story: Ik wil leren hoe ik het OO-principe encapsulation toepas op mijn project

### Issue Details

**Labels:** `K5::OOP`<br>`Type::Learning Story`

**1. Inleiding**

Object georiënteerd programmeren (OOP) leunt op een aantal pijlers: abstraction, encapsulation, inheritance en polymorfisme. De pijler `encapsulation` is onderwerp van deze learning story.

Het idee achter OOP is dat methoden en eigenschappen toebehoren aan specifieke objecten (zie ook abstraction). Het moment dat je besluit om die eigenschappen en methoden onder te brengen in hun eigen `class`, moet je ook garanties inbouwen dat die eigenschappen en methoden niet zomaar van buitenaf kunnen worden gewijzigd of aangeroepen.

Neem bijvoorbeeld de `class` docent. Docenten hebben hun eigen eigenschappen en methoden: zo hebben ze een naam, leeftijd, en bepaalde gedragingen. Het zou gek zijn als iemand van buitenaf, zonder autorisatie, kan besluiten om een docent een andere naam te geven. Of als een student, zonder toestemming van de docent, besluit om cijfers in de cijferadministratie te wijzigen. Encapsulation garandeert dat die docent-eigenschappen, en de gedragingen, niet zomaar door anderen gebruikt kunnen worden.

Het OO-principe *encapsulation* (ook wel "inkapseling") helpt je om je code op een georganiseerde en veilige manier te ontwerpen. Je verbergt interne details van *classes* en laat alleen de belangrijkste functionaliteit naar buiten zien. Dit maakt het gemakkelijker om je code te organiseren en te onderhouden.

**2. Wat moet ik kunnen?**

- [ ] Je kunt *access modifiers* instellen voor attributen en methoden (zoals `public`, `private` en `protected`).
- [ ] Je kunt *getters* en *setters* maken voor attributen en deze op de juiste manier gebruiken.

**3. Hoe leer ik dit?**

- [ ] Knowledgebase: encapsulation en/of
- [ ] Weblinks naar videocourses, boeken, websites over dit onderwerp, specifiek gericht op de programmeertaal waarin gewerkt wordt binnen de betreffende leerroute.

---

## Learning story: Ik wil leren hoe ik het OO-principe abstraction toepas op mijn project

### Issue Details

**Labels:** `K5::OOP`<br>`Type::Learning Story`

**1. Inleiding**

Object georiënteerd programmeren (OOP) leunt op een aantal pijlers: abstraction, encapsulation, inheritance en polymorfisme. De pijler `abstraction` is onderwerp van deze learning story.

Neem een object uit de echte wereld in gedachten, bijvoorbeeld een waterfles. Je weet precies wat er bedoeld wordt met een waterfles zonder dat er details worden gegeven. Je maakt dus een eigen voorstelling van een waterfles in je hoofd. Maar ondanks het gebrek aan gedetailleerde informatie, weet je wat een waterfles is (eigenschappen) en wat je ermee kunt doen (gedrag). Dit is het proces van abstraction, je brengt als het ware een object terug naar zijn meest basale vorm, oftewel zijn abstracte vorm.

**2. Wat moet ik kunnen?**

Je kunt een klasse ontwerpen en implementeren met:

- [ ] Eigenschappen (attributen).
- [ ] Gedrag (methodes).

**3. Hoe leer ik dit?**

- [ ] Knowledgebase: abstraction en/of
- [ ] Weblinks naar videocourses, boeken, websites over dit onderwerp, specifiek gericht op de programmeertaal waarin gewerkt wordt binnen de betreffende leerroute.

---

## Learning story: Ik wil leren hoe ik het OO-principe inheritance toepas op mijn project

### Issue Details

**Labels:** `K5::OOP`<br>`Type::Learning Story`

**1. Inleiding**

Object georiënteerd programmeren (OOP) leunt op een aantal pijlers: abstraction, encapsulation, inheritance en polymorfisme. De pijler `inheritance` is onderwerp van deze learning story.

Object-oriented programming (OOP) draait erom dat we in programma's proberen om de werkelijkheid te vatten. Wat je vaak ziet is dat, wanneer we proberen om categorieen te maken, dat we daar eindeloos mee door kunnen gaan. Zo heeft de HvA docenten, maar zijn sommige docenten meer gelijk dan anderen. Elke docent staat voor de klas, maar de ene docent heeft zich misschien gespecialiseerd in programmeren, een ander in het opstellen van een business plan, en een derde in het inrichten van infrastructuren. Daardoor heeft elke docent bepaalde basistaken, maar afhankelijk van de specialisatie heeft een individuele docent eigen kenmerken, kennis, of aanvullende taken die hij of zij kan uitvoeren.

De manier om dit principe naar OOP te vertalen noemen we Inheritance (overerving). Inheritance helpt bij het hergebruiken van code en het organiseren van objecten. Met inheritance kunnen we bijvoorbeeld een basis-class(parent) `Voertuig` creëren met algemene eigenschappen, zoals het aantal wielen en de maximale snelheid. Afgeleide classes zoals `Auto`, `Vrachtwagen` en `Motorfiets` erven deze eigenschappen en voegen specifieke kenmerken toe, zoals het aantal deuren en het laadvermogen. Dit bevordert een efficiënte en gestructureerde code, waarbij we gemeenschappelijke functionaliteit op één plek neerzetten en specifieke functionaliteit toevoegen in subclasses(childs).
Inheritance maakt het onderhouden en uitbreiden van de code gemakkelijker, waardoor we flexibele en herbruikbare code kunnen schrijven, zoals in dit voorbeeld het modelleren van auto's en andere voertuigen.

```mermaid
classDiagram
    Voertuig <|-- Auto
    Voertuig <|-- Vrachtwagen
    Voertuig <|-- Motorfiets
    Voertuig : -String merknaam
    Voertuig : -int aantalWielen
    Voertuig : -int maximaleSnelheid
    Voertuig : getMerknaam()
    
    class Auto{
      -int aantalDeuren
      -boolean heeftDakdragers
      getAantalDeuren()
    }
    class Vrachtwagen{
      -int laadvermogen
      -boolean heeftSlaapcabine
      getLaadvermogen()
    }
    class Motorfiets{
      -int aantalCC 
      -boolean heeftZijspan
      getAantalCC()
    }
```

**2. Wat moet ik kunnen?**

- [ ] Je kunt een parent class maken met gemeenschappelijke eigenschappen en gedrag.
- [ ] Je kunt verschillende child classes maken die van een parent class overerven.

**3. Hoe leer ik dit?**

- [ ] Knowledgebase: inheritance en/of
- [ ] Weblinks naar videocourses, boeken, websites over dit onderwerp, specifiek gericht op de programmeertaal waarin gewerkt wordt binnen de betreffende leerroute.

---

## Learning story: Ik wil leren hoe ik een relationele database ontwerp en implementeer

### Issue Details

**Labels:** `K6::Relationele Database`<br>`Type::Learning Story`

Stel je voor... Het is 1950, en in een rokerig kantoor moet je voor een klant een factuur uitschrijven. Eerst zoek je op in de rolodex wat het adres is van de klant. Daarna speur je door je werkbonnen om te achterhalen wat er precies voor de klant is gedaan. Op de prijslijst kijk je wat de kosten daarvoor zijn, en uiteindelijk tel je alles bij elkaar op. Je schrijft alle gegevens op de factuur, en voor de zekerheid neem je het ook over in je eigen kasboek, inclusief uniek factuurnummer, die je eens per week controleert tegen de bijboekingen van de bank. Het is een heel proces, waar de kleinste spelfout geld kost!

Gelukkig hebben we, ruim 70 jaar later, een makkelijkere manier om al deze informatie te bewaren: de relationele database. Wat vroeger een proces was van meerdere informatiesystemen controleren, documenten toevoegen aan een veelvoud van mappen, en meerdere uren werk, is nu versimpelt dankzij een efficient en effectief database management system. Het risico van dubbele gegevens is verdwenen door het toepassen van een `single point of truth`. En in een database raak je zelden een haastig geschreven notitie kwijt!

**Wat ga ik leren?**

In dit learning story ga je leren hoe je zelf een relationele database ontwerpt en implementeert. Een relationele database kan je gebruiken om gegevens in op te slaan. Met de taal SQL praat je met deze database. Ook is er speciale software waarmee je een database kan aanmaken en beheren. Je leert het hele proces van conceptualisatie tot implementatie. Je gaat eerst databases ontwerpen in concept, en een `Entiteit-Relatie Diagram` (oftewel `ERD`) maken. Deze vertaal je daarna naar een database-specifiek ontwerp, een `Extended Entity-Relationship Diagram`, oftewel een `EER`. Met behulp van `Primary Keys` en `Foreign Keys` ga je de relaties tussen tabellen van de database aangeven. Daarnaast leer je hoe je bestaande gegevens klaar kan maken voor de relationele database via `normalisatie`.

**Wat moet ik kunnen?**

- [ ]  Je kan een databasemodel ontwerpen van 4 of meer aan elkaar gerelateerde tabellen in een ERD.
- [ ]  Je kan geschikte datatypes kiezen voor de velden in je tabellen.
- [ ]  Je kan geschikt bereik kiezen voor  velden in je tabellen.
- [ ]  Je kan gepaste key identifiers kiezen voor je tabellen.
- [ ]  Je kan de relaties aangeven tussen de verschillende tabellen.
- [ ]  Je kan ruwe gegevens normaliseren naar de derde normaalvorm.
- [ ]  Je kan een databasemodel omzetten naar een fysiek datamodel in een RDMS met een visuele interface.

**Hoe leer ik dit?**

- [Primary keys](https://www.w3schools.com/sql/sql_primarykey.asp)
- [Foreign keys](https://www.w3schools.com/sql/sql_foreignkey.asp)
- [SQL constraints](https://www.w3schools.com/sql/sql_constraints.asp)
- Knowledge base: [Relationele Database](https://propedeuse.hbo-ict-hva.nl/1_beroepstaken/software/ontwerpen/relationele_databases/0_relationele_databases/)

---

## Learning story: Ik wil leren hoe ik SQL gebruik om met een database te kunnen werken

### Issue Details

**Labels:** `K6::Relationele Database`<br>`Type::Learning Story`

Veruit de meest-gebruikte manier om gegevens digitaal op te slaan is de (relationele) database. Van gebruikersgegevens tot blogposts, van zakelijke transacties tot highscores, zelfs plaatjes of hele liedjes kan je veilig en efficient bewaren in een database. We zijn een heel eind gekomen sinds de tijd van geprinte formuliertjes en uitpuilende multo-mappen vol afschriften.

Toch hebben databases eigen, nieuwe uitdagingen. Zo is het nog knap lastig om precies die gegevens op te vragen die je nodig hebt. En databases zijn weliswaar efficient, maar daardoor slaan ze zelden alle relevante informatie in een enkele tabel op - het koppelen van gegevens uit meerdere tabellen is daardoor (bijna) altijd nodig. Deze uitdagingen navigeren, en slim oplossen, ga je leren aan de hand van deze user story.

**Wat ga ik leren?**

Een database is een systeem om digitaal gegevens te beheren. De meeste databases zijn relationeel. Dit betekent dat gegevens worden opgeslagen in tabellen. Met behulp van *primary keys* en *foreign keys* worden relaties gelegd tussen tabellen. Relationele databases hebben een taal om gegevens naar een database te schrijven en gegevens uit een database te lezen, de *Structured Query Language (SQL)*.

**Wat moet ik kunnen?**

Je gaat met behulp van SQL gegevens opslaan in je eigen database. Je hebt hiervoor in elk geval het *INSERT statement* nodig. Nog mooier is het als je ook gegevens kunt wijzigen (met *UPDATE*) of verwijderen (met *DELETE*).
Natuurlijk moet je ook gegevens uit de database kunnen lezen. Hiervoor gebruik je een *SELECT-query*. Je kunt met een query gegevens uit één tabel tegelijk lezen, maar je kunt ook gegevens uit meer dan één tabel tegelijk ophalen.

- [ ] Queries kunnen uitvoeren op een relationele database met Database Management software (DMS) zoals PHP MyAdmin of MySQL workbench.
- [ ] `SELECT` statements.
- [ ] `INSERT` statements.
- [ ] `UPDATE` statements.
- [ ] `DELETE` statements.
- [ ] `SELECT` statements waarbij je gegevens uit meerdere tabellen haalt middels `JOIN`s.
- [ ] `SELECT` statements waarin je informatie sorteert, samenvoegt, of gebruikt in berekeningen.
- [ ] `SELECT` statements waarbij je records opvraagt via wildcards, in combinatie met het `LIKE`-statement.

**Hoe leer ik dat?**

Hieronder vind je een selectie aan lesmateriaal dat je kunt gebruiken om te starten met relationele databases en SQL (de taal die je gebruikt om te communiceren met een database). Het lesmateriaal is in de vorm van video courses, websites en e-books. Overigens is dit materiaal niet verplicht, maar we raden het je wel sterk aan. Ook kun je de [HBO-ICT Knowledgebase](https://knowledgebase.hbo-ict-hva.nl/) raadplegen. Kies het materiaal dat het beste bij je past en ga lekker aan de slag!

- VIDEO COURSE: [Programming Foundations: Databases (via LinkedIn Learning)](https://www.linkedin.com/learning/programming-foundations-databases-2?u=2132228) *Inleiding op relationele databases.*
- VIDEO COURSE: [Introduction to MySQL (via O'Reilly)](https://learning-oreilly-com.rps.hva.nl/videos/-/9781491982334/continue) *Een handige video course over o.a. SQL en hoe je daarmee gegevens in een database ophaalt, opslaat, bewerkt en verwijdert.*
- WEBSITE: [W3Schools SQL tutorial](https://www.w3schools.com/sql/default.asp) *Prima SQL tutorial voor de starter met bij ieder topic voorbeelden en kleine oefeningen. Tevens een handig naslagwerk voor als je meer ervaren bent*.

---

## Als gebruiker wil ik ... zodat ik

### Issue Details

**Labels:** `K2::User Stories opstellen`

**Titel**
De titel van de User Story beschrijft de focus. Deze is vanuit de behoefte van een gebruiker opgesteld.

#### Beschrijving

In de beschrijving geef je details over de User Story en schets je de context.

??? note "Definitions of Done"

    #### Definitions of Done

    Door het opstellen en aanhouden van Definitions Of Done, zorg je ervoor dat het werk wat je aflevert ook daadwerkelijk gebruikt kan worden. Deze zijn grotendeels generiek over het project.
    Hieronder staan een aantal vaak voorkomende DoD die je kan gebruiken in je User Story.

    - [ ] Alle acceptatie criteria zijn behaald
    - [ ] Het werk is gedocumenteerd, zodat een teamlid hiermee verder kan
    - [ ] Het werk is geschreven in Standaardnederlands
    - [ ] Het werk staat op de gitlab repository
    - [ ] Het werk is gereviewd door een peer

##### Software specifiek

- [ ] De code is opgesteld volgens de HBO-ICT code conventions
- [ ] De code is handmatig functioneel getest op fouten
- [ ] De code werkt zonder fouten bij normaal gebruik

#### Acceptatie criteria

Acceptatie criteria zijn specifieke eisen aan waaraan de User Story moet voldoen. Deze zijn meestal uniek per User Story.

- [ ] ...
- [ ] ...
- [ ] ...

---

## Learning Story: Ik wil leren hoe ik agile kan werken volgens de Scrum methodiek

### Issue Details

**Labels:** `K1::User stories werken`<br>`Type::Learning Story`

Scrum is een manier om samen als team in kleine stappen te werken en op te leveren. Scrum is in 1995 geïntroduceerd om beter te leren en samenwerken in een team en zo complexe problemen op te lossen. De term Scrum komt uit het rugby, waarbij een team samenkomt om de bal steeds naar voren te krijgen.
Met Scrum werk je gericht aan je project in Sprints (iteraties). Binnen iedere Sprint voer je de volgende stappen uit: Sprint Planning, Daily Stand-ups, Sprint Review en Sprint Retrospective.

Bij het ontwikkelen van software wordt scrum ook regelmatig toegepast. Doordat je elke dag start met een Daily Stand-up weet je waar teamleden aan werken. Je bespreekt ook eventuele obstakels die je die dag kan tegenkomen, waardoor je die doelen niet bereikt. Doordat je elke dag start met een overleg verbeter je de communicatie tussen teamleden, en werk je sneller naar het einddoel.

Tijdens je project houd je je planning bij in een Sprint Backlog.
Zowel dit backlog als je werk (documentatie en code) manage je in de Gitlab omgeving.  

**Wat moet ik leren?**
Leer over de standaard Scrum concepten en activiteiten:

- [ ] Scrum uitgangspunten
- [ ] User Stories
- [ ] Sprint en product Backlog
- [ ] Sprint Planning
- [ ] Daily Stand-up
- [ ] Sprint Review
- [ ] Sprint Retrospective

Voor jouw project werk je volgens Scrum, leer hoe je de nodige stappen kan uitvoeren met Gitlab voor Scrum:

- [ ] het inrichten van een Board voor je Sprint
- [ ] het indelen van user stories en learning stories in een Sprint
- [ ] het toewijzen van een persoon aan een story
- [ ] het toewijzen van een weight aan een story
- [ ] het wijzigen van een status van een user of learning story (bijv. van to-do naar doing)
- [ ] het wijzigen van de inhoud van een story (bijv. toevoegen van bronnen, requirements, definitions of done)
- [ ] het koppelen van een commit van code of documentatie aan een specifieke user story
- [ ] het opslaan van mijn documentatie (markdown bestanden) in de daarvoor bedoelde map op de main branch
- [ ] het opslaan van mijn code in de main branch

**Hoe leer ik dat?**
<https://knowledgebase.hbo-ict-hva.nl/2_professional_skills/toekomstgericht_organiseren/managen/scrum/>

***Original sources***  

[Gitlab and Scrum mapping](https://about.gitlab.com/blog/2018/03/05/gitlab-for-agile-software-development/)  
[Gitlab documentation](https://gitlab.fdmci.hva.nl/help)  
  
***Secondary sources***  
[Book, Gitlab Quickstart Guide](https://lib.hva.nl/permalink/31UKB_UAM2_INST/1btjd75/alma9939262938105132)  
  
***Advanced Gitlab knowledge***  
[Book, Mastering Gitlab 12](https://lib.hva.nl/discovery/fulldisplay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,contains,gitlab&offset=0)

**Aan welke Kwaliteitscriteria of Gedragscriteria is dit gerelateerd?**  
K1. Je hebt de meeste van de user stories afgerond.

---

## Learning story: ik wil aantonen dat ik werk volgens kwaliteitscriteria

### Issue Details

**Labels:** `G4::Kwaliteitsnormen`<br>`K2::User Stories opstellen`<br>`K3::Prototyping`<br>`K4::Gebruikerstest`<br>`K6::Relationele Database`<br>`K7::UML`<br>`Type::Learning Story`

In het vorige project heb je over een aantal kwaliteitscriteria geleerd. In dit blok ga je die opnieuw toepassen. Je gebruikt coding conventions, documenteert je code, communiceert professioneel en gestructureerd.

**Wat moet ik kunnen?**

- [ ] Coding conventions gebruiken
- [ ] Code op de juiste manier technisch documenteren
- [ ] Professioneel schriftelijk communiceren
- [ ] Gestructureerde documenten schrijven
- [ ] Vooraf nadenken over wanneer een user story aan eisen voldoet

---

## Learning Story: Ik wil aantonen dat ik gestructureerde en begrijpelijke documentatie schrijf

### Issue Details

**Labels:** `K2::User Stories opstellen`<br>`K3::Prototyping`<br>`K7::UML`<br>`Type::Learning Story`

Bij het schrijven van het gebruikersonderzoek, reflecties of bij de beschrijving van UML-diagram wordt in blok 2 gelet op actief schrijven. Verder ga je teksten goed structureren zodat elke lezer de gedachte achter jouw ontwerp, product of software goed kan volgen. Dat betekent dat je schrijft in korte alinea’s met koppen. Spelling en grammaticafouten leiden af en kunnen ook tot onduidelijkheid leiden; je schrijft daarom ook foutloos. Je schrijft semi-formeel omdat te joviaal of te formeel taalgebruik ook kan leiden tot miscommunicatie.

Bij het schrijven van het gebruikersonderzoek, reflecties of bij de beschrijving van UML-diagram wordt in blok 2 gelet op actief schrijven. Verder ga je teksten goed structureren zodat elke lezer de gedachte achter jouw ontwerp, product of software goed kan volgen. Dat betekent dat je schrijft in korte alinea’s met koppen. Spelling en grammaticafouten leiden af en kunnen ook tot onduidelijkheid leiden; je schrijft daarom ook foutloos. Je schrijft semi-formeel omdat te joviaal of te formeel taalgebruik ook kan leiden tot miscommunicatie.

**Wat moet ik kunnen?**

- [ ] Actief schrijven
- [ ] (Bijna) foutloos schrijven [volgens criteria van stijlgids](https://propedeuse.hbo-ict-hva.nl/1_beroepstaken/basisvaardigheden/taalvaardigheden/stijlgids_taal/)
- [ ] Gestructureerd documenteren met alinea's, titels en tussenkoppen

**Hoe leer ik dit?**

- [Knowledge base: Documenteren](https://knowledgebase.hbo-ict-hva.nl/2_professional_skills/doelgericht_interacteren/communiceren/documenteren/
)
- [Knowledge base: Stijlgids taal](https://propedeuse.hbo-ict-hva.nl/1_beroepstaken/basisvaardigheden/taalvaardigheden/stijlgids_taal/)

---

## Learning story: ik wil aantonen dat ik constructief kan samenwerken

### Issue Details

**Labels:** `K1::User stories werken`<br>`K2::User Stories opstellen`<br>`Type::Learning Story`

Samenwerken in een project waarin je met z'n tweeën werkt is niet alleen belangrijk voor het succes van dat specifieke project, maar het ontwikkelt ook waardevolle vaardigheden die in allerlei situaties van pas komen. Het stelt je in staat om effectief te communiceren, te coördineren en problemen op te lossen. Samenwerking is een hoeksteen van succes, of je nu in een tweepersoonsteam werkt of in een grotere groepssamenstelling.

**Wat moet ik kunnen?**

Ik kan aantonen dat ik  afspraken heb gemaakt met mijn medestudent
Ik kan aantonen dat ik een medestudent kan aanspreken wanneer dat nodig blijkt
Ik kan aantonen dat ik aan mijn medestudent feedback geef en vraag

**Hoe leer ik dat?**

- [ ] [Knowledge base: Samenwerkingscontract]( https://knowledgebase.hbo-ict-hva.nl/2_professional_skills/doelgericht_interacteren/samenwerken/0_samenwerken/)
- [ ] [Knowledge base: Feedback geven](https://knowledgebase.hbo-ict-hva.nl/2_professional_skills/persoonlijk_leiderschap/persoonlijke_ontwikkeling/feedback/0_feedback/)

---

## Learning story: ik wil leren hoe ik asynchrone taken kan uitvoeren vanuit mijn code

### Issue Details

**Labels:** `K5::OOP`<br>`Type::Learning Story`

**1. Inleiding**  
Asynchroon programmeren met JavaScript gaat om het schrijven van code die kan omgaan met taken die niet onmiddellijk worden uitgevoerd en daarom niet de uitvoering van de rest van de code mogen blokkeren. Dit kan worden bereikt met behulp van asynchrone functies.

**2. Wat moet ik leren?**  
Met behulp van JavaScript asynchrone functies gebruiken om gegevens van een andere bron (zoals een API) in te laden op je website.

**3. Hoe leer ik dit?**  

- VIDEO COURSE: [Lesson 5: Asynchronous Programming in JavaScript (via O'Reilly)](https://learning-oreilly-com.rps.hva.nl/videos/learn-to-program/9780137560387/9780137560387-LPJ1_01_05_00) *Uit de video course 'Learn to Program with Javascript' gaat Lesson 5 over asynchrone functies en promises*

**4. Aan welke Kwaliteitscriteria of Gedragscriteria is dit gerelateerd?**  
K5. Je hebt object georiënteerd geprogrammeerd en maak gebruik van objectgeoriënteerde technieken zoals abstraction, inheritance en encapsulation.

---

## Learning Story: Ik wil leren hoe ik in p5.js keyboard input kan afhandelen in mijn website

### Issue Details

**Labels:** `K5::OOP`<br>`Type::Learning Story`

**1. Inleiding**  
Interactiviteit in p5js kan je toevoegen door de input van met muis en toetsenbord uit te lezen en daarop te handelen.

**2. Wat moet ik leren?**  

- [ ] detecteren als een toets is ingedrukt
- [ ] een handeling uitvoeren bij een specifieke toets
- [ ] de handeling stoppen als er geen toets meer is ingedrukt

**3. Hoe leer ik dit?**  
[P5js interactivity](https://p5js.org/learn/interactivity.html)

[Book: Learn JavaScript with P5js: Hoofdstuk 11.Events "Using KeyPressed"](
https://lib.hva.nl/discovery/fulldisplay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,contains,p5.js&offset=0)

**4. Aan welke Kwaliteitscriteria of Gedragscriteria is dit gerelateerd?**
K5. Je hebt object georiënteerd geprogrammeerd en maak gebruik van objectgeoriënteerde technieken zoals abstraction, inheritance en encapsulation.

---

## Learning Story: Ik wil leren hoe ik in OOP objecten over het scherm laat bewegen in p5.js
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

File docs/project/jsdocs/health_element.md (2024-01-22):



## HealthElement
Class representing a health element.
This element can be picked up by the player to increase their health.

**Kind**: global class  

* [HealthElement](#HealthElement)
    * [new HealthElement()](#new_HealthElement_new)
    * [.update(dT)](#HealthElement+update)

### new HealthElement()
Constructor for Health Element

### healthElement.update(dT)
Method for updating the health element's properties and drawing it on the screen.
This checks whether the player is close enough, if this is the case, it will be picked up.
Picking it up increases the player's health by the amount specified in the constructor.

**Kind**: instance method of [<code>HealthElement</code>](#HealthElement)  

| Param | Type | Description |
| --- | --- | --- |
| dT | <code>number</code> | The time passed since the last update, in seconds. |

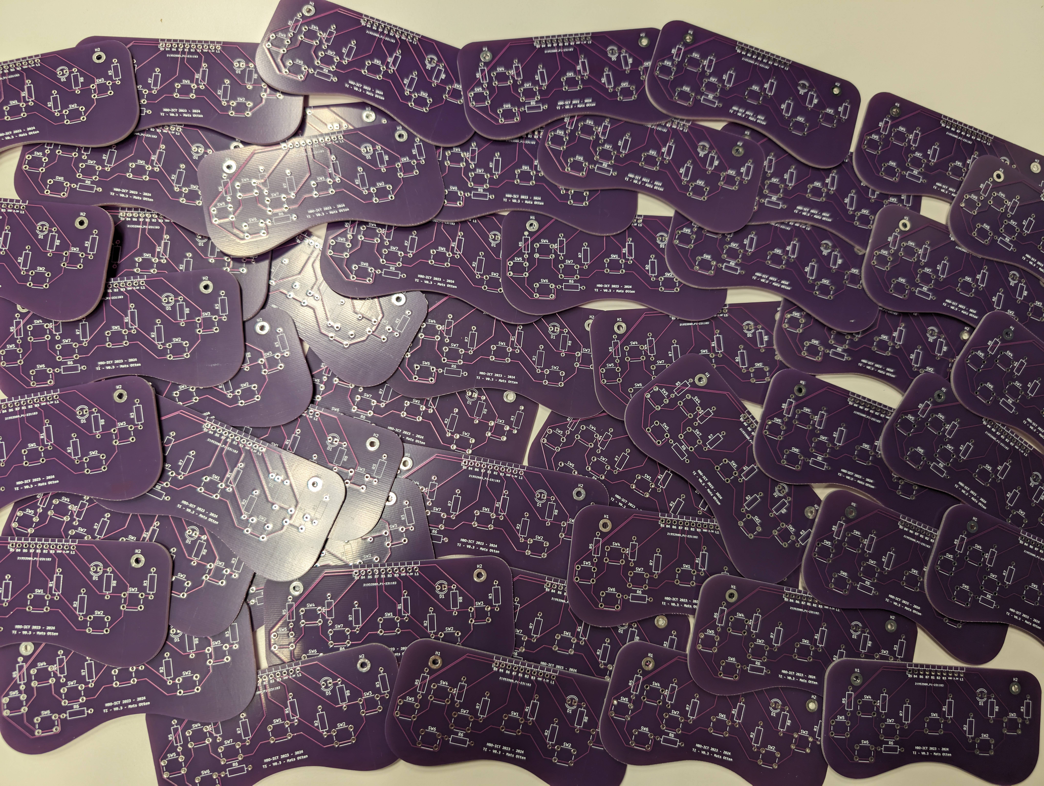
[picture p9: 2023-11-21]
docs/assets/headers/game_controller_pcbs.jpg

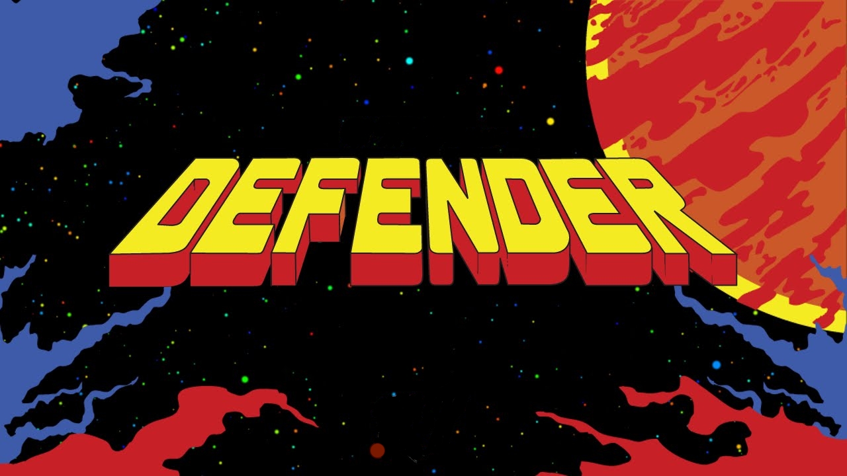
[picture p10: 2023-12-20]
web/assets/title_screen.jpeg

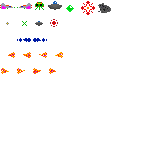
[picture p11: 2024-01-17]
web/assets/spritesheet.png

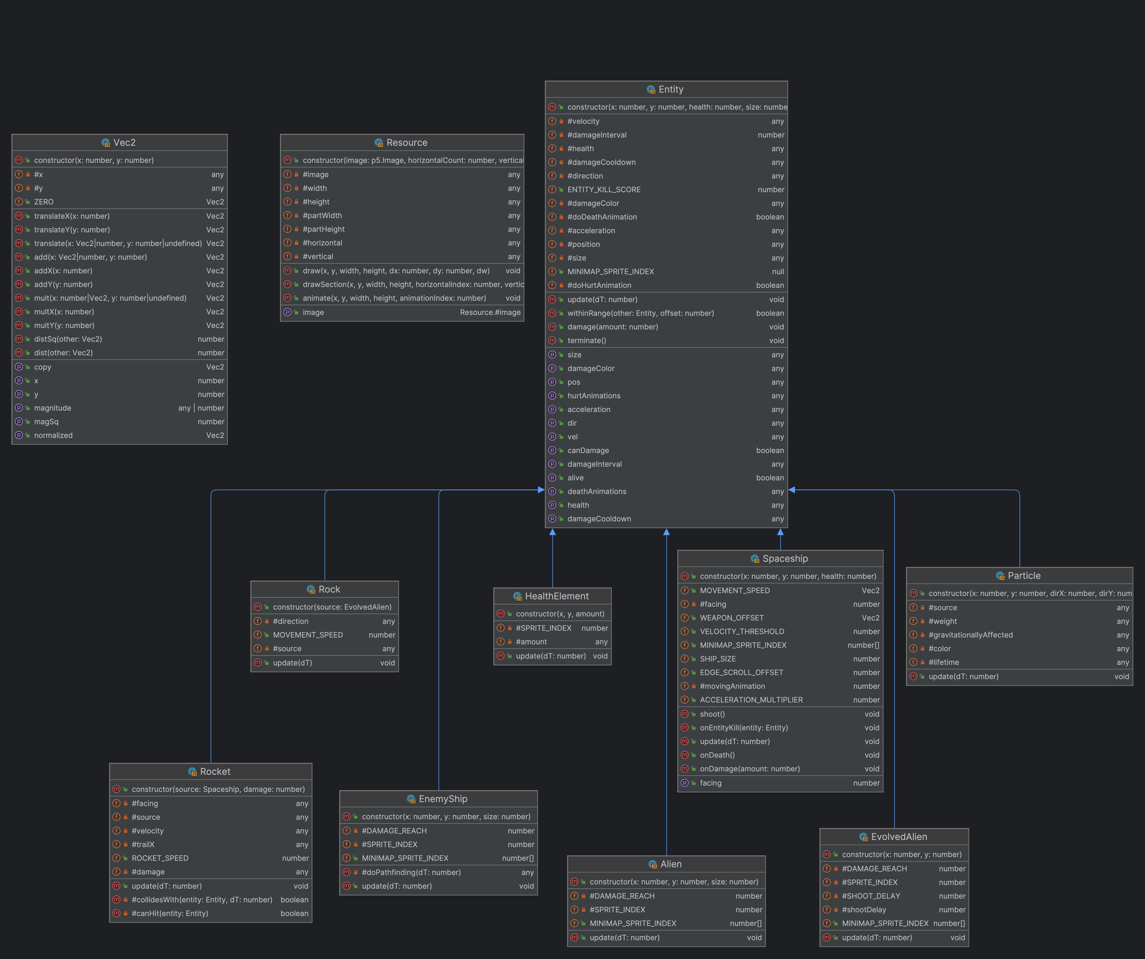
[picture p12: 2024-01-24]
uml/UML Class Diagram.png

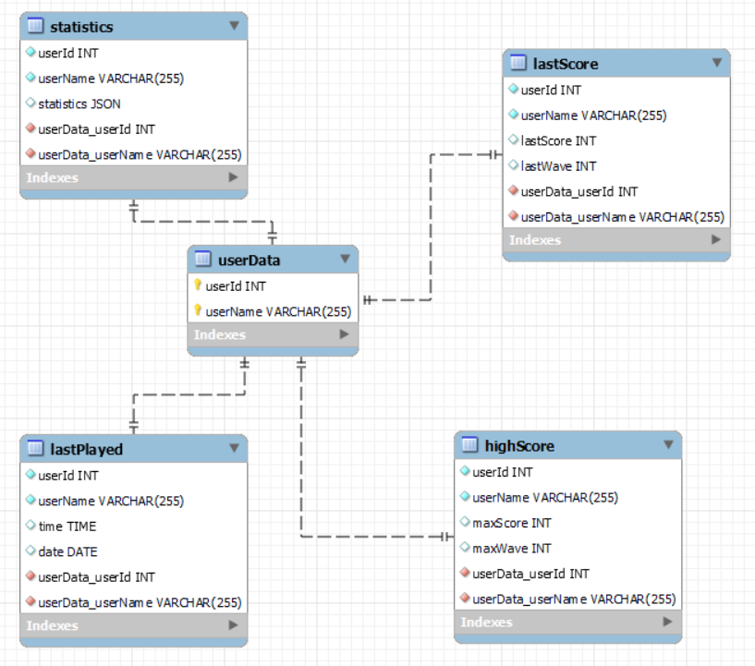
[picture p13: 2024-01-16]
uml/EER.png

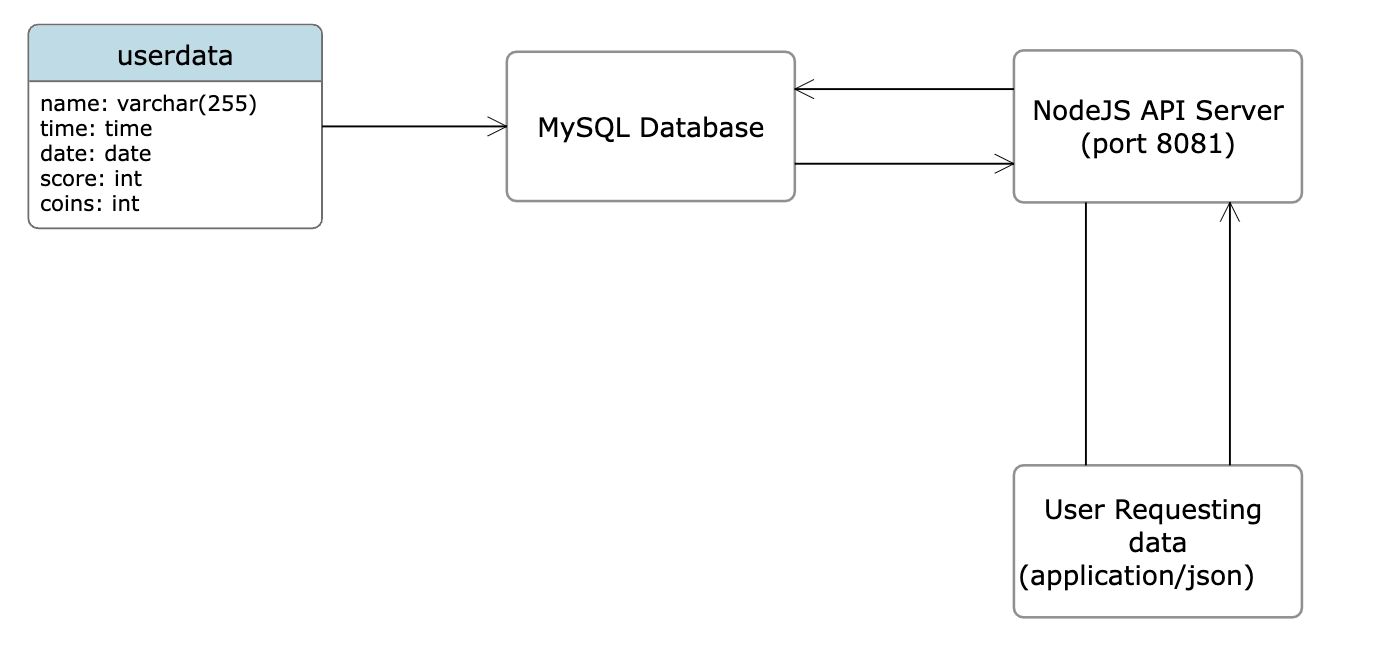
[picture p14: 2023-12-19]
uml/UML Database.png

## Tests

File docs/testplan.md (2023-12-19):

# Test Plan

---

> ## Plan No. 1 (Gameplay):
> 
> We vragen aan onze gebruiker om het spel voor 2 minuten te spelen.
> Hierna vragen wij aan deze gebruiker of er bepaalde hindernissen waren waar
> hij/zij tegenaan liepen.
> 
> Deze feedback kunnen we vervolgens toe passen aan de algemene game functionaliteit.

> ## Plan No. 2 (User-Interface): 
> 
> We vragen aan onze gebruiker om kort door de UI heen te gaan, zonder externe
> assistentie. Na 2 minuten vragen we de gebruiker om te stoppen en vragen we
> of er hindernissen waren en/of alles in de UI gemakkelijk genoeg te gebruiken was.
> Hierop vragen we feedback. Deze kunnen we vervolgens toepassen op de UI.

> ## Plan No. 3 (Score systeem)
> 
> We vragen aan onze gebruiker om kort het spel voor 2 minuten te spelen en
> te proberen punten te verkrijgen. Na deze 2 minuten vragen we de gebruiker of
> het verkrijgen van punten duidelijk genoeg was en/of hier nog verbeteringen in 
> te maken zijn.

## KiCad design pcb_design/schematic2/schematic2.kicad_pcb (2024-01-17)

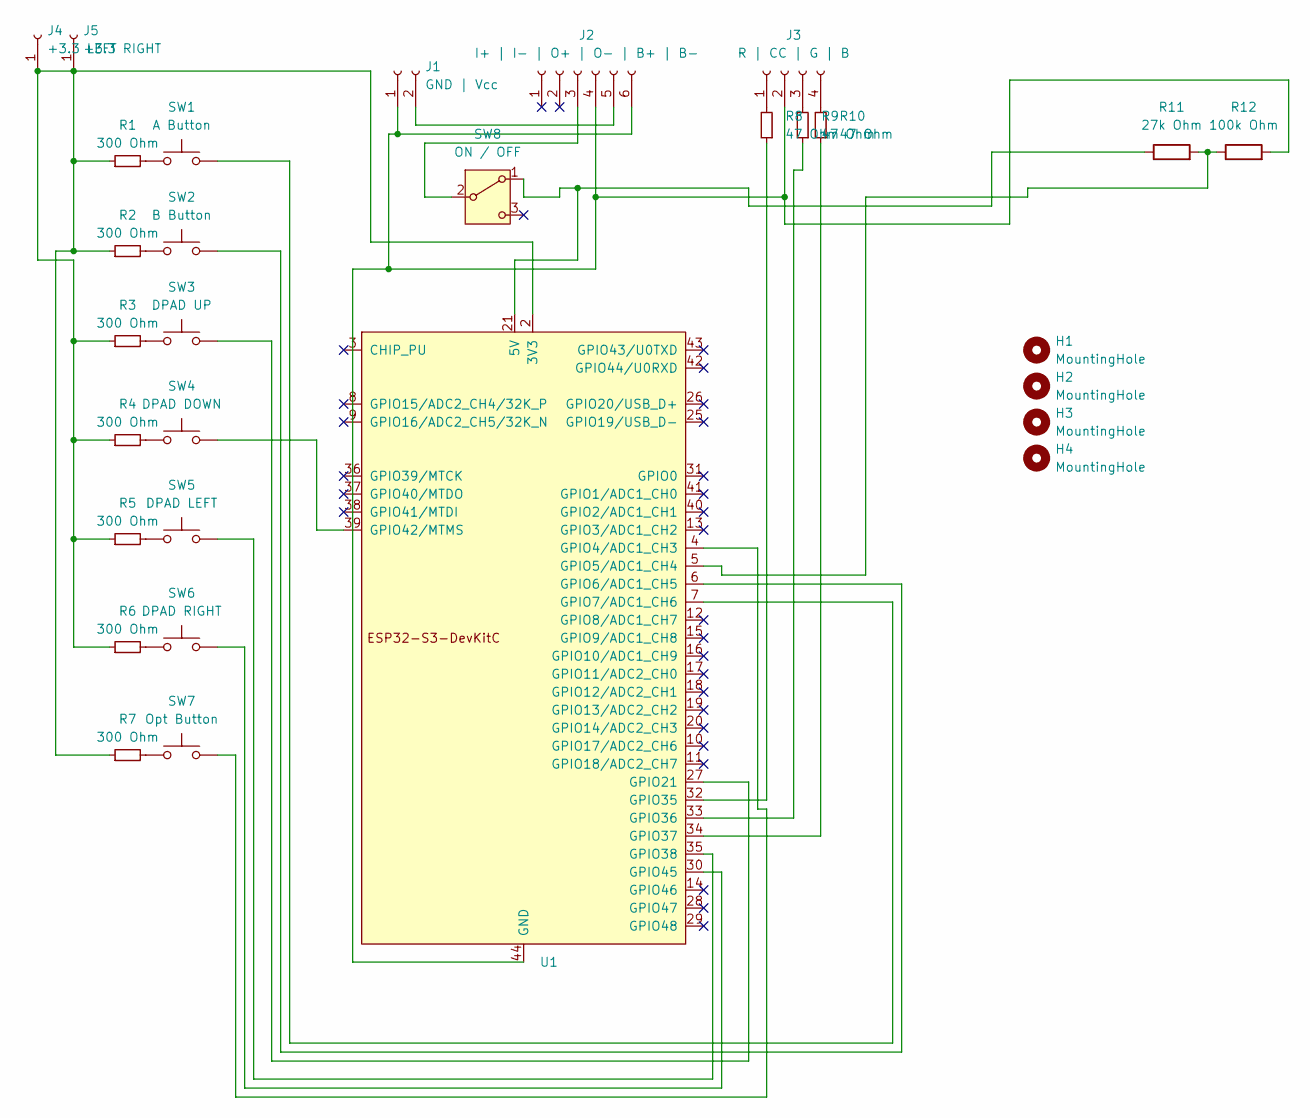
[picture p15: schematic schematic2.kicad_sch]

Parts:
H1, H2, H3, H4: MountingHole; MountingHole_2.5mm_Pad
J1: GND | Vcc; SolderWire-1.5sqmm_1x02_P7.8mm_D1.7mm_OD3.9mm
J2: I+ | I- | O+ | O- | B+ | B-; TP4056-Module
J3: R | CC | G | B; LED_D5.0mm-4_RGB
J4: +3.3 LEFT; MountingHole_2.5mm_Pad
J5: +3.3 RIGHT; MountingHole_2.5mm_Pad
R1, R2, R3, R4, R5, R6, R7: 300 Ohm; R_Axial_DIN0207_L6.3mm_D2.5mm_P10.16mm_Horizontal
R8, R9, R10: 47 Ohm; R_Axial_DIN0207_L6.3mm_D2.5mm_P10.16mm_Horizontal
R11: 27k Ohm; R_Axial_DIN0207_L6.3mm_D2.5mm_P10.16mm_Horizontal
R12: 100k Ohm; R_Axial_DIN0207_L6.3mm_D2.5mm_P10.16mm_Horizontal
SW1: A Button; SW_PUSH_6mm
SW2: B Button; SW_PUSH_6mm
SW3: DPAD UP; SW_PUSH_6mm
SW4: DPAD DOWN; SW_PUSH_6mm
SW5: DPAD LEFT; SW_PUSH_6mm
SW6: DPAD RIGHT; SW_PUSH_6mm
SW7: Opt Button; SW_PUSH_6mm
SW8: ON / OFF; PinSocket_1x03_P2.54mm_Vertical
U1: ESP32; ESP32S3_Dev_Module

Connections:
unnamed: J1.1, J2.4, J2.6, J3.2, R12.2, U1.22 (GND), U1.23 (GND), U1.24 (GND), U1.44 (GND)
unnamed: J1.2, J2.5
unnamed: J2.3, SW8.2 (B)
unnamed: J3.1, R8.2
unnamed: J3.3, R9.2
unnamed: J3.4, R10.2
unnamed: J4.1, J5.1, R1.1, R2.1, R3.1, R4.1, R5.1, R6.1, R7.1, U1.1 (3V3), U1.2 (3V3)
unnamed: R1.2, SW1.1
unnamed: R2.2, SW2.1
unnamed: R3.2, SW3.1
unnamed: R4.2, SW4.1
unnamed: R5.2, SW5.1
unnamed: R6.2, SW6.1
unnamed: R7.2, SW7.1
unnamed: R11.1, SW8.1 (A), U1.21 (5V)
unnamed: SW7.2, U1.4 (GPIO4/ADC1_CH3)
unnamed: R11.2, R12.1, U1.5 (GPIO5/ADC1_CH4)
unnamed: SW2.2, U1.6 (GPIO6/ADC1_CH5)
unnamed: SW1.2, U1.7 (GPIO7/ADC1_CH6)
unnamed: SW3.2, U1.27 (GPIO21)
unnamed: R8.1, U1.32 (GPIO35)
unnamed: R9.1, U1.33 (GPIO36)
unnamed: R10.1, U1.34 (GPIO37)
unnamed: SW5.2, U1.35 (GPIO38)
unnamed: SW4.2, U1.39 (GPIO42/MTMS)
unnamed: SW6.2, U1.30 (GPIO45)

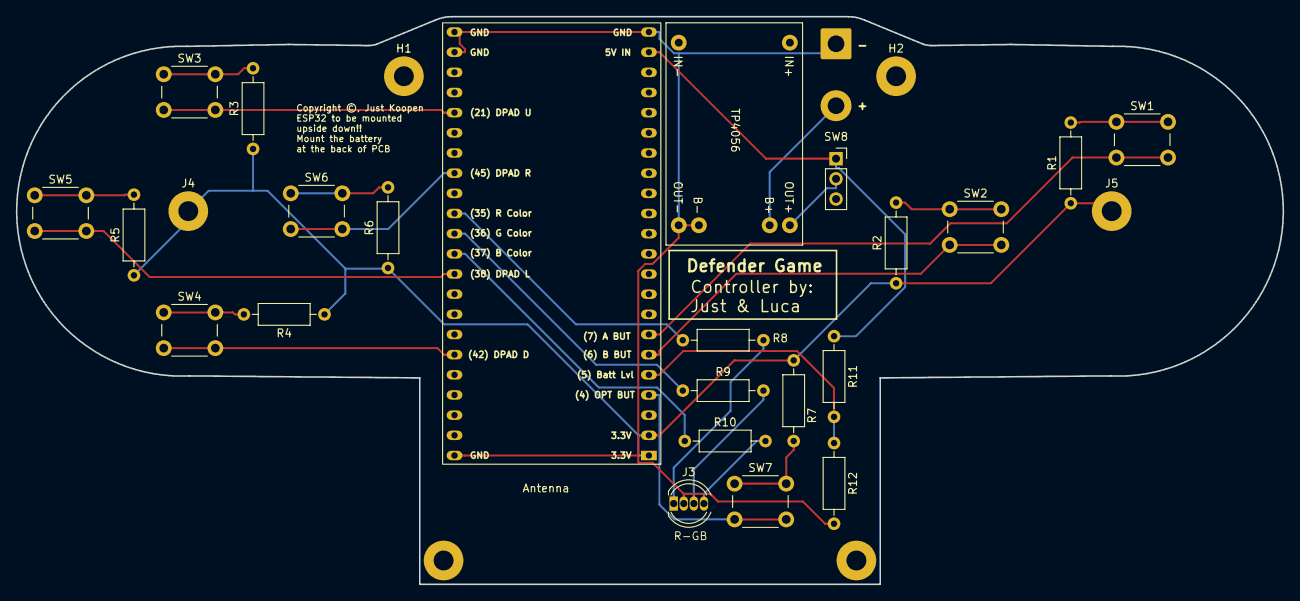
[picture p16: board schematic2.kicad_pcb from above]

Board: 2 copper layers, 159.5 x 71.5 mm, 30 parts (0 on the bottom side), 26 nets.

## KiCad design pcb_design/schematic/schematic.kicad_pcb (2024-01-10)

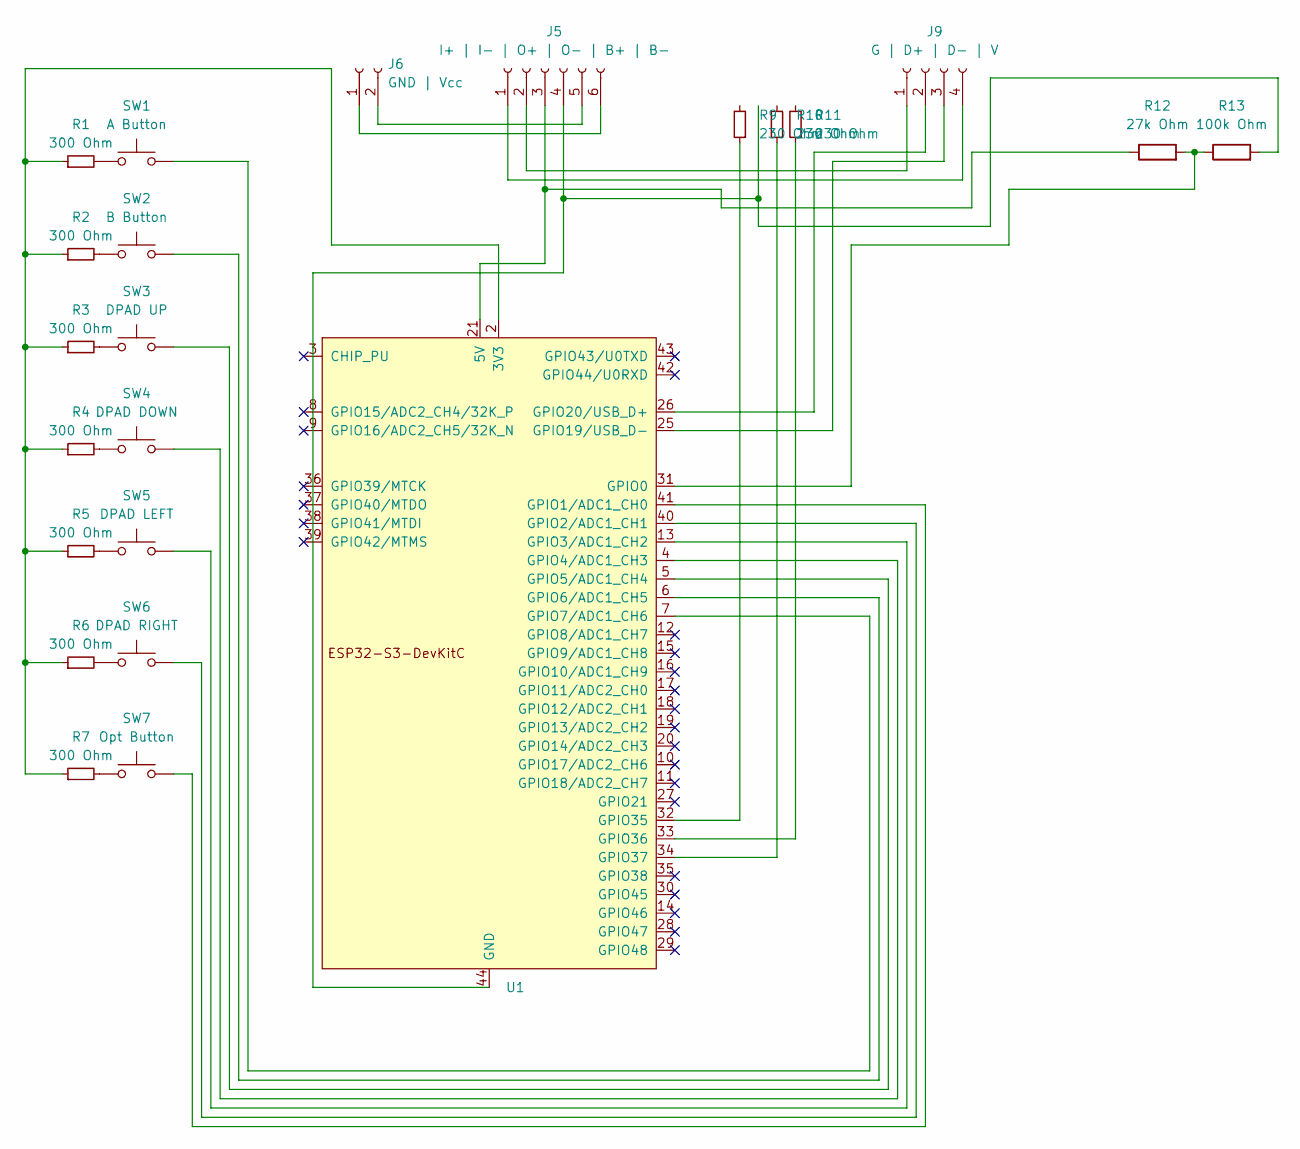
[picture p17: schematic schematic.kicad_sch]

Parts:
J5: I+ | I- | O+ | O- | B+ | B-; TP4056-Module
J6: GND | Vcc; SolderWire-2sqmm_1x02_P7.8mm_D2mm_OD3.9mm
J9: G | D+ | D- | V; PinHeader_1x04_P2.54mm_Vertical
R1, R2, R3, R4, R5, R6, R7: 300 Ohm; R_Axial_DIN0207_L6.3mm_D2.5mm_P10.16mm_Horizontal
R9, R10, R11: 230 Ohm; R_Axial_DIN0207_L6.3mm_D2.5mm_P10.16mm_Horizontal
R12: 27k Ohm; R_Axial_DIN0207_L6.3mm_D2.5mm_P10.16mm_Horizontal
R13: 100k Ohm; R_Axial_DIN0207_L6.3mm_D2.5mm_P10.16mm_Horizontal
SW1: A Button; SW_PUSH_6mm
SW2: B Button; SW_PUSH_6mm
SW3: DPAD UP; SW_PUSH_6mm
SW4: DPAD DOWN; SW_PUSH_6mm
SW5: DPAD LEFT; SW_PUSH_6mm
SW6: DPAD RIGHT; SW_PUSH_6mm
SW7: Opt Button; SW_PUSH_6mm
U1: ESP32; ESP32-S3-DevKitC

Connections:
unnamed: J5.1, J9.4
unnamed: J5.2, J9.1
unnamed: J5.3, R12.1, U1.21 (5V)
unnamed: J5.4, R13.2, U1.22 (GND), U1.23 (GND), U1.24 (GND), U1.44 (GND)
unnamed: J5.5, J6.2
unnamed: J5.6, J6.1
unnamed: J9.2, U1.26 (GPIO20/USB_D+)
unnamed: J9.3, U1.25 (GPIO19/USB_D-)
unnamed: R1.1, R2.1, R3.1, R4.1, R5.1, R6.1, R7.1, U1.1 (3V3), U1.2 (3V3)
unnamed: R1.2, SW1.1
unnamed: R2.2, SW2.1
unnamed: R3.2, SW3.1
unnamed: R4.2, SW4.1
unnamed: R5.2, SW5.1
unnamed: R6.2, SW6.1
unnamed: R7.2, SW7.1
unnamed: R12.2, R13.1, U1.31 (GPIO0)
unnamed: SW7.2, U1.41 (GPIO1/ADC1_CH0)
unnamed: SW6.2, U1.40 (GPIO2/ADC1_CH1)
unnamed: SW5.2, U1.13 (GPIO3/ADC1_CH2)
unnamed: SW4.2, U1.4 (GPIO4/ADC1_CH3)
unnamed: SW3.2, U1.5 (GPIO5/ADC1_CH4)
unnamed: SW2.2, U1.6 (GPIO6/ADC1_CH5)
unnamed: SW1.2, U1.7 (GPIO7/ADC1_CH6)
unnamed: R9.1, U1.32 (GPIO35)
unnamed: R11.1, U1.33 (GPIO36)
unnamed: R10.1, U1.34 (GPIO37)

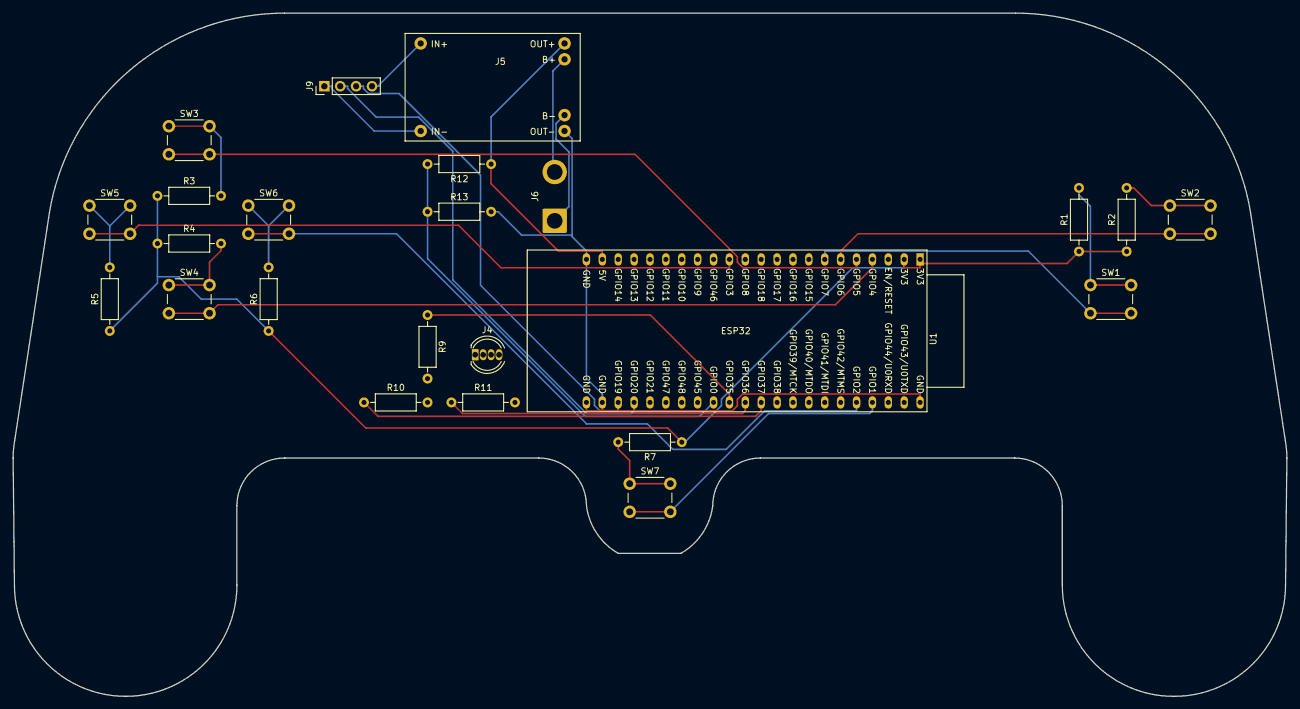
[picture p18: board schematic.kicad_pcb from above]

Board: 2 copper layers, 203.6 x 109.2 mm, 24 parts (0 on the bottom side), 27 nets.

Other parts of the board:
J4: R | CC | B | G; LED_D5.0mm-4_RGB

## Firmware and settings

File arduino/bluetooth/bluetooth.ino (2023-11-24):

/*
  Rui Santos
  Complete project details at https://RandomNerdTutorials.com/esp32-web-bluetooth/

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
  The above copyright notice and this permission notice shall be included in all
  copies or substantial portions of the Software.
*/

#include <BLEDevice.h>
#include <BLEServer.h>
#include <BLEUtils.h>
#include <BLE2902.h>

// Port indices for all buttons / LEDs
#define PIN_BUTTON_UP     3
#define PIN_BUTTON_LEFT   8
#define PIN_BUTTON_RIGHT  9
#define PIN_BUTTON_DOWN  46
#define PIN_BUTTON_A     12
#define PIN_BUTTON_B     11
#define PIN_BUTTON_OPT   10
#define PIN_LED           4
#define PIN_JOYSTICK_X   13
#define PIN_JOYSTICK_Y   14

// Bit position definitions of all buttons
#define BUTTON_UP_BP      0
#define BUTTON_LEFT_BP    1
#define BUTTON_RIGHT_BP   2
#define BUTTON_DOWN_BP    3
#define BUTTON_A_BP       4
#define BUTTON_B_BP       5
#define BUTTON_OPT_BP     6

#define DEVICE_BT_NAME "ESP32 Controller"

uint8_t * controller_data = (uint8_t *) malloc(4);

BLEServer *pServer = NULL;
BLECharacteristic *pSensorCharacteristic = NULL;
// BLECharacteristic* pLedCharacteristic = NULL;
bool deviceConnected = false;
bool oldDeviceConnected = false;
bool debugMode = false;

// See the following for generating UUIDs:
// https://www.uuidgenerator.net/

#define SERVICE_UUID "73770700-a4e0-4ff2-bd68-47a5250d5ec2"
#define CHARACTERISTIC_UUID "544a3ce0-5ca6-411e-a0c2-17789dc0cec8"

class connectionCallback : public BLEServerCallbacks
{
  void onConnect(BLEServer *pServer)
  {
    deviceConnected = true;
  };

  void onDisconnect(BLEServer *pServer)
  {
    deviceConnected = false;
  }
};

void definePinModes()
{

  pinMode(PIN_LED, OUTPUT);
  pinMode(PIN_BUTTON_A, INPUT);
  pinMode(PIN_BUTTON_B, INPUT);
  pinMode(PIN_BUTTON_UP, INPUT);
  pinMode(PIN_BUTTON_LEFT, INPUT);
  pinMode(PIN_BUTTON_RIGHT, INPUT);
  pinMode(PIN_BUTTON_DOWN, INPUT);
  pinMode(PIN_BUTTON_OPT, INPUT);
  pinMode(PIN_JOYSTICK_X, INPUT);
  pinMode(PIN_JOYSTICK_Y, INPUT);
}

void toggleDebugMode(){
  delay(100);
  if(digitalRead(PIN_BUTTON_B) && digitalRead(PIN_BUTTON_LEFT)){
    debugMode = true;
    Serial.print("Debug mode enabled!");

    digitalWrite(PIN_LED, HIGH);
    delay(100);
    digitalWrite(PIN_LED, LOW);
    delay(100);
    digitalWrite(PIN_LED, HIGH);
    delay(100);
    digitalWrite(PIN_LED, LOW);
    delay(100);
    digitalWrite(PIN_LED, HIGH);
    delay(600);
    digitalWrite(PIN_LED, LOW);
  }
}

void debugPrint(String text){
  if (debugMode)
  {
    Serial.println(text);
  }
}

void readInput()
{
  controller_data[0] = (uint8_t)(
    (digitalRead(PIN_BUTTON_A) << BUTTON_A_BP) |
    (digitalRead(PIN_BUTTON_B) << BUTTON_B_BP) | 
    (digitalRead(PIN_BUTTON_UP) << BUTTON_UP_BP) |
    (digitalRead(PIN_BUTTON_LEFT) << BUTTON_LEFT_BP) | 
    (digitalRead(PIN_BUTTON_RIGHT) << BUTTON_RIGHT_BP) |
    (digitalRead(PIN_BUTTON_DOWN) << BUTTON_DOWN_BP)
    );
  
  uint16_t x = analogRead(PIN_JOYSTICK_X);
  uint16_t y = analogRead(PIN_JOYSTICK_Y);

//Serial.printf("x: %.1f, y: %.1f\r\n", (float) (x * 0.0879120879), (float) (y * 0.0879120879));

  controller_data[1] = (uint8_t) ((x >> 4) & 0xFF);
  controller_data[2] = (uint8_t) (((x & 0xF) << 4 | (y >> 8) & 0xF) & 0xFF);
  controller_data[3] = (uint8_t) (y & 0xFF);
}

void setup()
{
  Serial.begin(115200);
  definePinModes();
  //toggleDebugMode();
  analogReadResolution(12);

  // Create the BLE Device
  BLEDevice::init(DEVICE_BT_NAME);

  // Create the BLE Server
  pServer = BLEDevice::createServer();
  pServer->setCallbacks(new connectionCallback());

  // Create the BLE Service
  BLEService *bleService = pServer->createService(SERVICE_UUID);

  // Create a BLE Characteristic
  pSensorCharacteristic = bleService->createCharacteristic(
      CHARACTERISTIC_UUID,
      BLECharacteristic::PROPERTY_READ | BLECharacteristic::PROPERTY_WRITE | BLECharacteristic::PROPERTY_NOTIFY | BLECharacteristic::PROPERTY_INDICATE);

  // Create a BLE Descriptor
  pSensorCharacteristic->addDescriptor(new BLE2902());

  // Start the service
  bleService->start();

  // Start advertising
  BLEAdvertising *pAdvertising = BLEDevice::getAdvertising();
  pAdvertising->addServiceUUID(SERVICE_UUID);
  pAdvertising->setScanResponse(false);
  pAdvertising->setMinPreferred(0x0); // set value to 0x00 to not advertise this parameter
  BLEDevice::startAdvertising();
  debugPrint("Waiting a client connection to notify...");
}

void loop()
{
  // notify changed value
  if (deviceConnected)
  {
    digitalWrite(PIN_LED, HIGH);
    readInput();
    pSensorCharacteristic->setValue(controller_data, 4);
    pSensorCharacteristic->notify();

    //debugPrint("Message sent:");
    //debugPrint(String(data));

    delay(10); // bluetooth stack will go into congestion, if too many packets are sent, in 6 hours test i was able to go as low as 3ms
  }
  // disconnecting
  if (!deviceConnected && oldDeviceConnected)
  {
    digitalWrite(PIN_LED, LOW);
    debugPrint("Device disconnected.");
    delay(500);                  // give the bluetooth stack the chance to get things ready
    pServer->startAdvertising(); // restart advertising
    debugPrint("Start advertising");
    oldDeviceConnected = deviceConnected;
  }
  // connecting
  if (deviceConnected && !oldDeviceConnected)
  {
    // do stuff here on connecting
    oldDeviceConnected = deviceConnected;
    debugPrint("Device Connected");
    digitalWrite(PIN_LED, HIGH);
    delay(100);
    digitalWrite(PIN_LED, LOW);
  }
}

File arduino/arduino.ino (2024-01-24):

#include "USB.h"
#include "USBHIDKeyboard.h"

#define PIN_BUTTON_UP 21
#define PIN_BUTTON_LEFT 38
#define PIN_BUTTON_RIGHT 45
#define PIN_BUTTON_DOWN 42
#define PIN_BUTTON_A 6
#define PIN_BUTTON_B 7
#define PIN_BUTTON_OPT 4
#define PIN_LED 4
#define PIN_BATTERY 5

#define PIN_LED_RED 35
#define PIN_LED_GREEN 36
#define PIN_LED_BLUE 37

#define BUTTON_UP_KEY ((uint8_t)'w')
#define BUTTON_LEFT_KEY ((uint8_t)'a')
#define BUTTON_RIGHT_KEY ((uint8_t)'d')
#define BUTTON_DOWN_KEY ((uint8_t)'s')
#define BUTTON_A_KEY ((uint8_t)' ')
#define BUTTON_B_KEY ((uint8_t)'f')
#define BUTTON_OPT_KEY ((uint8_t)'r')

#define BUTTON_COUNT 7

const uint8_t button_keys[BUTTON_COUNT] = {BUTTON_A_KEY, BUTTON_B_KEY, BUTTON_LEFT_KEY, BUTTON_UP_KEY, BUTTON_RIGHT_KEY, BUTTON_DOWN_KEY, BUTTON_OPT_KEY};
const uint8_t button_pins[BUTTON_COUNT] = {PIN_BUTTON_A, PIN_BUTTON_B, PIN_BUTTON_LEFT, PIN_BUTTON_UP, PIN_BUTTON_RIGHT, PIN_BUTTON_DOWN, PIN_BUTTON_OPT};
const uint8_t led_pins[3] = {PIN_LED_RED, PIN_LED_GREEN, PIN_LED_BLUE};

void setRGB(uint32_t argb);

USBHIDKeyboard keyboard;

uint8_t key_states = 0;

void setup() {

  // set LED pins to output
  for (uint8_t i = 0; i < 3; i++)
    pinMode(led_pins[i], OUTPUT);

  // Set all button pins to input
  for (uint8_t i = 0; i < BUTTON_COUNT; i++) 
    pinMode(button_pins[i], INPUT);

  // initialize control over the keyboard:
  keyboard.begin();
  USB.begin();
  
  setRGB(0x4000FF00); // Set RGB light to green
}

/** 
 * Method for changing the rgb values of the LED on the controller. 
 * Argument can be provided in the following format: AARRGGBB (hexadecimal)
 */
void setRGB(uint32_t argb) {
  for (uint8_t i = 0; i < 3; i++) 
    analogWrite(led_pins[i], (uint8_t) (((argb >> ((2 - i) * 8)) & 0xFF) * (((argb >> 24) & 0xFF) / 255.0f)));
}

// Main loop
void loop() {

  // Whenever a button is pressed or released, we want to check the difference between the last state and its current state
  // If these differ, we send a 'release' or 'press' report.
  uint8_t previous = key_states, diff, i = 0, state = 0;
  key_states = 0;
  for (; i < BUTTON_COUNT; i++) {

    state = digitalRead(button_pins[i]);
    key_states |= state << i;
    diff = (state - ((previous >> (BUTTON_COUNT - i - 1)) & 1));

    // If there is a change in button state, press or release it.
    if (diff) {
      keyboard.press((uint8_t) button_keys[i]);
    } else { 
      keyboard.release((uint8_t) button_keys[i]);  
    }
  }
}

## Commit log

2023-11-21 Wrote serial code and pin readings
2023-11-22 Added code for reading and sending button data
2023-11-23 Changed pin readout method to char array
2023-11-28 Reverted joystick functionality, added back regular input buttons
2023-11-28 Added filters to BLE Service
2023-11-29 fucked around with arduino.ino and found out
2023-11-30 Sorted files, added pause, play and settings button
2023-12-01 Added Serial coms to website and esp32
2023-12-06 Added battery readings and db connection
2023-12-08 Added OPT button functionality
2024-01-06 Added real battery checking
2024-01-07 Changed battery voltages
2024-01-07 Changed battery readings again
2024-01-10 Added PCB schematics and layout design files
    [schematic.kicad_pcb, schematic.kicad_sch]
2024-01-10 PCB schematic files
    [schematic2.kicad_pcb, schematic2.kicad_sch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]
2024-01-10 Update schematic2.kicad_sch file
    [schematic2.kicad_pcb, schematic2.kicad_sch]
2024-01-12 Added switch to PCB design and fixed battery readings
    [schematic2.kicad_pcb, schematic2.kicad_sch]
2024-01-16 Reverted arduino code to a previous (working) version
    [arduino.ino]
2024-01-16 Reverted arduino.ino
2024-01-17 Updated arduino code
2024-01-17 kicad files
    [schematic2.kicad_pcb, schematic2.kicad_sch]
2024-01-19 more kicad files
2024-01-22 Update navigation and add PCB result image
2024-01-23 Added circuit.md
2024-01-23 Remove material-extensions plugin and add pymdownx.emoji and pymdownx.highlight plugins
2024-01-23 Fix typo and add new button option
    [arduino.ino]
2024-01-23 Updated arduino.ino, made changes to game functionality
2024-01-23 Transferred BLEGamepad.ino content to arduino.ino, deleted BLEGamepad.ino
2024-01-24 Add RGB LED initialization and delay in setup() function
2024-01-24 Removed comments from arduino.ino
2024-01-24 Updated arduino.ino; Minimized code

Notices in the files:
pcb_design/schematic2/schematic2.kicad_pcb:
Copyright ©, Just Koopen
